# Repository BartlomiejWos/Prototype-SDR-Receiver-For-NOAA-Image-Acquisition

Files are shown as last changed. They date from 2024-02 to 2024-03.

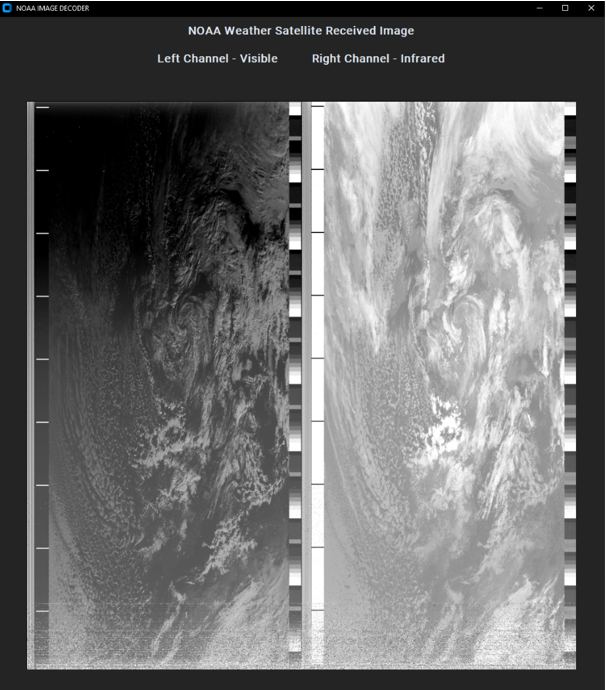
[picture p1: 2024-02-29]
images/decoder.png

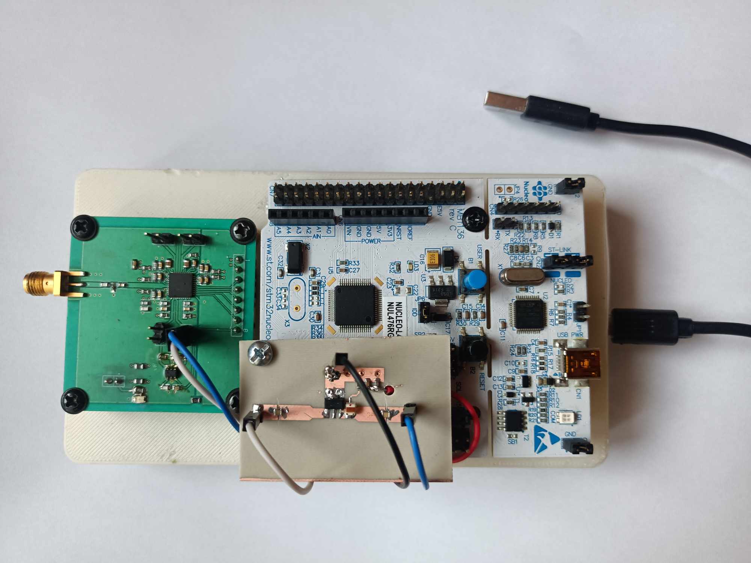
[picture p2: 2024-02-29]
images/sdr.jpg

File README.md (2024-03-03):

# Data acquisition from the NOAA meteoroligal satellite using DIY radio prototype based on the idea of Software Defined Radio (SDR) - Engineering Thesis Project   

## The purpose of this project was to design and fabricate a receiver, based on the idea of SDR, with appropriate software, to acquire weather images from NOAA's satellites (operating at 137 MHz).

This project is an example showing you how to create simple SDR receiver for narrowband applications. Parts of the project shows how do the following: 
* Create a radio front-end PCB using Direct Conversion Receiver (DCR) Integrated Circuit CMX994, MAX2607 (Local Oscillator - LO) and ADL5611 (LO amplifier).
* Analog-to-digital processing and interface handling using STM32.
* Creation of software application enabling the observation of the spectrum of received signals and signal processing to decode the received data into an image.
* All steps have been detailed in the engineering thesis in the Polish language.

## Complete Device:
sdr

## Software written in python for spectral analysis and signal recording:
gui

## NOAA image decoder:
decoder

## PCB layout of radio front-end:
layout

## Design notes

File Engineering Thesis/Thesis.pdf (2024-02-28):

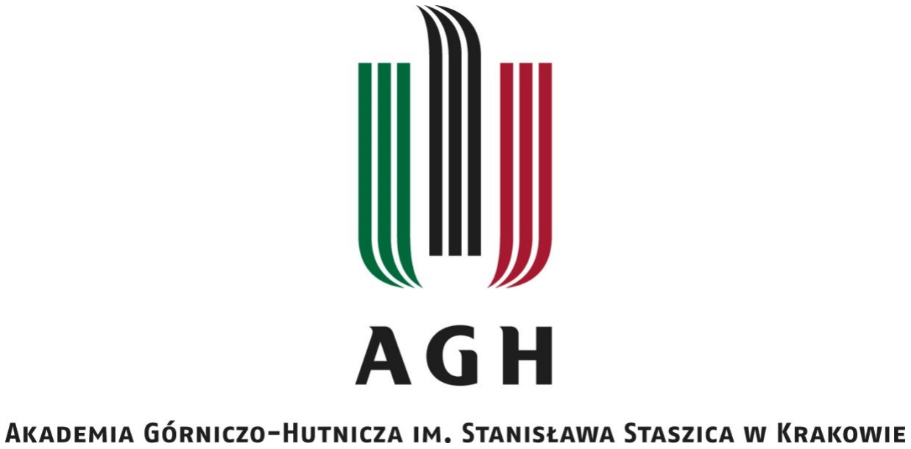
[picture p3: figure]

Wydział Informatyki, Elektroniki i Telekomunikacji

INSTYTUT ELEKTRONIKI

# Projekt dyplomowy

## Akwizycja danych z satelity meteorologicznego NOAA za pomocą prototypu radia bazującego na idei radia

definiowanego programowo (SDR).

## Data acquisition from the NOAA meteorological satellite using a radio prototype based on the idea of Software Defined

Radio.

Autor: | Bartłomiej Woś
Kierunek studiów: Elektronika i Telekomunikacja Opiekun pracy: dr inż. Robert Smolarz

Kraków, 2024

## Spis treści

1 Wstęp | 2
2 Model odbiornika definiowanego programowo | 3
3 Aplikacja komputerowa | 23
4 Badania i testy | 32
5 Podsumowanie | 37
Spis rysunków | 38
Spis tabel | 39
Literatura | 40
Załączniki | 43

## 1 Wstęp

Historia teledetekcji satelitarnej sięga połowy XIX wieku, kiedy to zostały wykonane pierwsze zdjęcia z balonu przez Gasparda Felixa Turnachon-Nadara [18].

Kolejnym kamieniem milowym było wykonanie serii zdjęć powierzchni Ziemi z wysokości ok. 120 km (czyli przekraczającej linię Karmana, będącą umowną

granicą między atmosferą Ziemi i przestrzenią kosmiczną) podczas lotu rakiety

balistycznej V2 [5]. W latach 60 XX wieku, Stany Zjednoczone rozpoczęły dwa

programy pozyskiwania zdjęć satelitarnych z kosmosu: wojskowy CORONA i cywilny TIROS (ang. Television Infrared Observation Satellite). Właśnie ten

ostatni został w 1978 roku przemianowany na program NOAA (ang. North

Oceanic and Atmospheric Adminstration). Seria satelitów TIROS-N/NOAA nadal

zapewnia codzienne obserwacje pogody na świecie. Satelity polarne NOAA krążą

po orbitach heliosynchronicznych, na wysokości ok. 790 - 870 km i okrążają Ziemię

14 razy dziennie. Ciekawostką jest to, że najstarszy z aktywnych satelitów -NOAA-15, jest na orbicie od 1998 roku. [13].

Celem niniejszej pracy inżynierskiej było zaprojektowanie oraz wykonanie odbiornika, bazującego na idei radia definiowanego programowo SDR (ang.

Software Defined Radio), wraz ze stosownym oprogramowaniem, umożliwiającym

pozyskanie zdjęć pogodowych z satelit NOAA starszego typu (pracujących na

częstotliwości 137 MHz). Praca składa się ze wstępu, dwóch rozdziałów

teoretycznych i jednego rozdziału praktycznego opisującego przeprowadzone

badania nad wykonanym urządzeniem oraz podsumowania. W rozdziale pierwszym

przeprowadzono analizę indywidualnych bloków funkcjonalnych służących do

akwizycji danych, w rozdziale drugim omówiono realizacje sprzętową i działanie

zaimplementowanej aplikacji komputerowej, natomiast rozdział trzeci został w

całości poświęcony przeprowadzonym pomiarom i testom zaprojektowanego

urządzenia. W zakończeniu przedstawiono podsumowanie wykonanych badań oraz

propozycje udoskonalenia zaprojektowanego urządzenia.

## 2 Model odbiornika definiowanego programowo

W niniejszym rozdziale skupiono się na analizie poszczególnych bloków

funkcjonalnych | służących | do | akwizycji | danych | odbieranych | z | satelit

meteorologicznych NOAA. W każdym podrozdziale przedstawiono kluczowe

elementy opracowanego systemu akwizycji, wybrane rozwiązania i dobór

oszacowanych wartości elementów. W podrozdziałach zawarto również niezbędne

symulacje oraz charakterystyki ułatwiające analize poszczególnych bloków.

### 2.1 Schemat blokowy

Na rysunku 2.1 przedstawiono schemat blokowy projektowanego urządzenia.

Fundamentalną rolę w rozpatrywanej strukturze pełni układ odbiornika o bezpośredniej przemianie częstotliwości DCR (ang. Direct Conversion Receiver ),

który jest jednym z popularniejszych rozwiązań stosowanych w odbiornikach
radiowych | [19]. | Proces | bezpośredniej | przemiany | częstotliwości | oznacza

sprowadzenie sygnału do pasma podstawowego (ang. Baseband). W kontekście

radia definiowanego programowo istotnym etapem jest jego dalsze przetworzenie

na reprezentacje cyfrową oraz transmisja do urządzenia docelowego takiego jak

komputer. Zabieg ten ma na celu dalszą obróbkę i dekododowanie pozyskanych

danych. | Odpowiednim | układem | zapewniającym | te | funkcjonalności | jest

mikrokontroler, którego zadaniem jest obsługa użytego bloku DCR oraz

komumunikacja z komputerem. Bloki funkcjonalne wchodzące w skład całego

systemu akwizycji, szczegółowo opisano w kolejnych podrozdziałach niniejszej

pracy.

Rysunek 2.1: Schemat blokowy projektowanego urządzenia typu SDR.

2.2 | Blok | odbiornika | bezpośredniej | przemiany

częstotliwości.

Omawiany | moduł | stanowi | jeden | z | najważniejszych | komponentów

projektowanego urządzenia odbiorczego. Jego sercem jest układ scalony CMX994,

pracujący w trybie DCR. W odróżnieniu od odbiorników heterodynowych z

podwójną przemianą częstotliwości, wybór architektury DCR przekłada się na

mniejszą złożoność toru radiowego. Dodatkowo przykładowe zastosowania układu

obejmują obszary takie jak radia definiowane programowo oraz komunikacja satelitarna [14], co sprawia, że wybrany element idealnie wpasowuje się w określone

założenia. Rysunek 2.2 przedstawia topologię układu CMX994 [14]. Rozpatrując

schemat mozna wyróżnić bloki funkcjonalne takie jak:
- zastosowany na wejściu niskoszumny wzmacniacz LNA (ang. Low Noise

Amplifier )
- tor przemiany częstotliwości zbudowany z dwóch mieszaczy, czterech filtrów

oraz układów wzmacniających
- rekonfigurowalny obwód oscylatora lokalnego
- wewnętrzny kontroler odpowiedzialny za komunikacje z układem

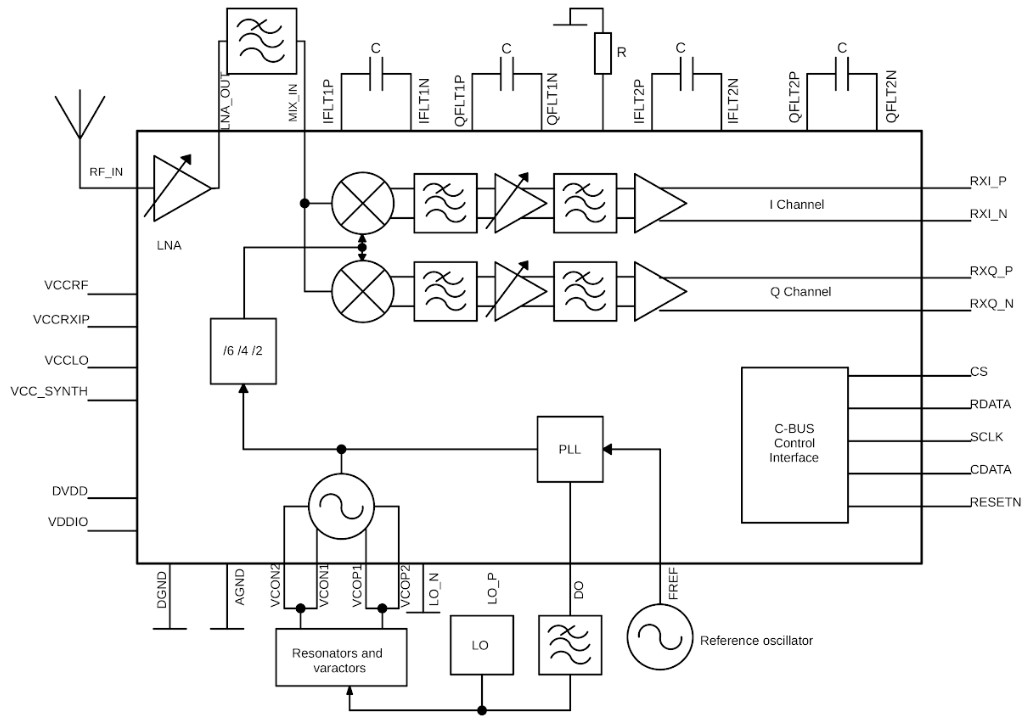
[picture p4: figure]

Rysunek 2.2: Schemat blokowy układu scalonego CMX994 [14].

Niezbędnym krokiem w celu prawidłowej pracy układu jest skonfigurowanie

rejestrów kontrolnych za pomocą magistrali C-BUS. Magistrala ta umożliwa komunikację z mikrokontrolerem za pomocą interfejsu SPI (ang. Serial Peripherial

Interface). Najważniejszymi rejestrami układu są General Control (Tabela 2.1)

oraz Rx Control (Tabela 2.2). Ich konfiguracja powinna być wykonana w

pierwszym | etapie | zintegrowania | projektowanego | odbiornika | DCR | z
mikrokontrolerem. Strukturę rejestrów na bazie noty katalogowej [14] ukazano

poniżej:

bit 7 | bit 6 | bit 5 | bit 4 | bit 3 | bit 2 | bit 1 | bit 0
En Bias | Freq2 | Freq1 | LP | VCOEN | PLLEN | RXEN | TXEN

Tabela 2.1: Rejestr General Control Układu Scalonego CMX944 [14].

bit 7 | bit 6 | bit 5 | bit 4 | bit 3 | bit 2 | bit 1 | bit 0
Mix Pwr | IQ Pwr | LNA Pwr | ACR Flt2 | ACR Flt1 | DC Range | DIV2 | DIV1

Tabela 2.2: Rejestr Rx Control Układu Scalonego CMX944 [14].

Detale dotyczące konkretnych ustawień oraz funkcji tych rejestrów można

znaleźć w dalszych sekcjach, w których szczegołówo omówiono istotne bloki

układu. Schemat elektryczny układu przedstawiono w załączniku 1.

### 2.2.1 Blok przemiany częstotliwości w układzie CMX994

Blok przemiany częstotliwości zastosowany w układzie CMX994 został

przedstawiony na Rysunku 2.3. Składa się on z dwóch torów radiowych dzięki, którym uzyskuje się dwie składowe: kwadraturową Q (ang. Quadrature) i

synfazową I (ang. In-phase). W kontekście cyfrowego przetwarzania sygnałów i

radia definiowanego programowo, odnosi się to do dwóch sygnałów przesuniętych w fazie o 90 stopni [12]. Rozpatrywany układ jest odbiornikiem z bezpośrednią

przemianą częstotliwości, toteż w pierwszej kolejności sygnał radiowy RF

pojawiący się na wejściu MIX IN jest mieszany z sygnałem oscylatora lokalnego LO (ang. Local Oscillator ) za pomocą mieszaczy diodowych. Po zestrojeniu

sygnału LO z sygnałem radiowym, w wyniku przemiany częstotliwości w ”dół”

uzyskuje się składowe Q oraz I o widmach przesuniętych do pasma podstawowego [19].

Aby umożliwić prawidłowe działanie bloku, układ mieszacza musi zostać

programowo włączony poprzez interfejs komunikacyjny. Służą do tego bity 1 i 7 rejestru General Control (Tabela 2.1) oraz bit 7 rejestru Rx Control (Tabela 2.2).

Tor radiowy kanałów IQ pasma podstawowego zawiera dwa dolnoprzepustowe

stopnie filtrujące oraz układy wzmacniające opisane w podrozdziale 2.2.3.

Wyprowadzenia obu kanałów zaprojektowano jako pary różnicowe, co należy

uwzględnić przy doborze mikrontrolera. Bloki filtrujące pozwalają na precyzyjną

konfiguracje | szerokości | pasma | w | odstępach | międzykanałowych | równych
odpowiednio 6.25 kHz, 12.5 kHz i 25 kHz [14]. Aby taka regulacja była możliwa,

dobrano odpowiednio kondesatory C18 − C21 ustalające częstotliwości graniczne

filtrów.

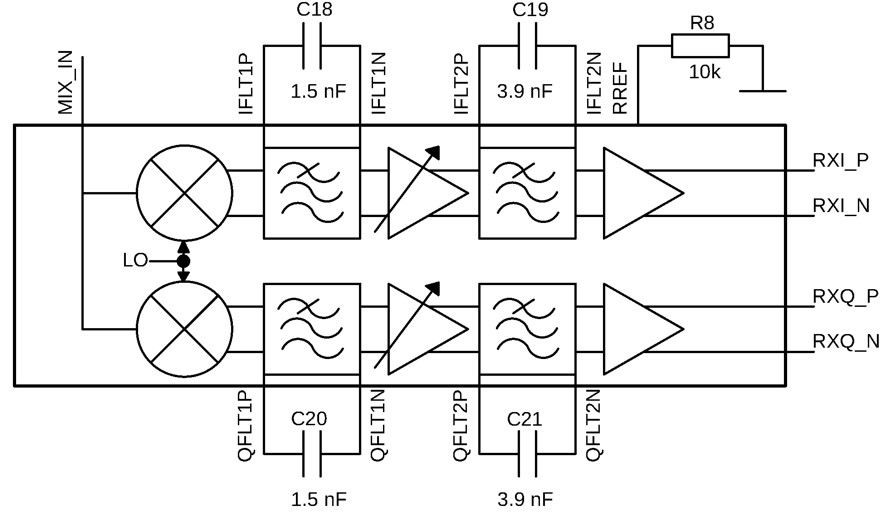
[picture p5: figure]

Rysunek 2.3: Blok przemiany częstotliwości układu scalonego CMX994 [14].

Pierwszy filtr umieszczony za układem mieszającym został zaprojektowany w

celu redukcji sygnałów blokujących. Nie jest on sterowany programowo i w

standardowej konfiguracji jest ustawiany na 4 - krotność wymaganej szerokości

pasma. Dla maksymalnego odstepu międzykanałowego tj. 25 kHz, częstotliwość przy której sygnał jest tłumiony o 3 dB powinna wynosić około 100 kHz [14].

Wartości elementów oszacowano za pomocą wzoru (2.1) dostępnego w nocie

katalogowej [14]:

C18,20 =

1
2π · f3dB · 20, 000

(2.1)

gdzie:

C18,20 - oszacowana wartość elementu

f3dB - częstotliwość graniczna filtru

Drugi filtr umieszczony za układem wzmacniającym, przeznaczony jest do

działania w pobliżu pasma podstawowego. Jego celem jest maksymalne

ograniczenie interferencji pochodzących z sąsiednich kanałów. Częstotliwość odcięcia filtru powinna wynosić między 30 % a 40 % szerokości najmniejszego

odbieranego pasma tj. 6.25 kHz oraz może być regulowana cyfrowo z

uwzględnieniem współczynnika skalującego 1:2:4 za pomocą bitów 3 - 4 rejestru Rx Control (Tabela 2.2). [14]. Konfiguracje bitów oraz odpowiadający im

współczynnik skalujący przedstawiono w Tabeli 2.3. Wartości kondesatorów, analogicznie jak w przypadku pierwszego filtru, obliczono za pomocą wzoru (2.2)

umieszczonego w nocie katalogowej [14]:

C19,21 =

1
2π · f3dB · 12, 000

(2.2)

gdzie:

C19,21 - oszacowana wartość elementu

f3dB - częstotliwość graniczna filtru

ACR flt2 | ACR flt1 | Współczynnik skalujący częstotliwości granicznej
0 | 0 | 2
0 | 1 | 4
1 | 0 | 8
1 | 1 | wartość zarezerwowana

Tabela 2.3: Współczynnik skalujący w zależności od konfiguracji bitów 3 - 4 rejestru Rx Control.

Rysunek 2.4 przedstawia charakterystyki amplitudowo - częstotliwościowe filtru

w zależności od konfiguracji bitów 3 - 4 rejestru Rx Control.

Rysunek 2.4: Charakterystyki amplitudowo – częstotliwościowe filtru w zależności od konfiguracji współczynnika skalującego [14].

### 2.2.2 Sekcja lokalnego oscylatora w układzie CMX944

Układ oscylatora lokalnego zwanego również heterodyną jest odpowiedzialny

za generowanie sygnału sinusoidalnego, który bierze udział w przemianie

częstotliwości razem z układem mieszacza. Odbiornik scalony CMX994 posiada

zintegrowany układ generatora o przestrajanej napięciowo częstotliwości VCO (ang. Voltage Controlled Oscillator ). Częstotliwość podstawowa wewnętrznego

VCO, jest ustalana za pomocą zewnętrznych elementów indukcyjnych oraz waraktorów [14]. Sekcja lokalnego oscylatora zawiera pętle synchronizacji fazowej

PLL (ang. Phase Locked Loop), którą można aktywować za pomocą bitu 2 rejestru

General Control (Tabela 2.1). Blok ten może współpracować zarówno z

wbudowanym lub zewnętrznym układem VCO. Podczas projektowania urządzenia

stwierdzono, że dostrojenie wewnętrznego VCO mogłoby być problematyczne, co

skłoniło | do | zastosowania | zewnętrznego | układu | scalonego. | Dodatkowo,

zrezygnowano z użycia układu PLL. Jako układ oscylatora sterowanego napięciem,

wybrano układ scalony z serii MAX2605 - 2609. Są to generatory sinusoidalne

pracujące w zakresie 45 MHz - 650 MHz, zaprojektowane specjalnie dla

przenośnych urządzeń komunikacji bezprzewodowej. Posiadają wbudowane

kondensatory sprzężenia zwrotnego oraz waraktory i z tego powodu jedynie zewnętrzna cewka jest wymagana do ustawienia częstotliwości oscylacji [9]. W celu

poprawnej obsługi zewnętrznego układu LO, należy aktywować blok VCO za pomocą bitu 3, oraz skonfigurować bity 5 - 6 rejestru General Control (Tabela

2.1). Odpowiadają one za dostosowanie amplitudy sygnału lokalnego oscylatora w

celu utrzymania równowagi fazy i parametrów szumowych mieszaczy odbiornika w wybranym zakresie częstotliwości [14]. Konfiguracje bitów 5 - 6 oraz

odpowiadający im zakres częstotliwości układu LO pokazano w poniższej tabeli:

bit Freq1 | bit Freq2 | Zakres częstotliwości LO (MHz)
0 | 0 | 100 - 150
0 | 1 | 150 - 300
1 | 0 | 300 - 700
1 | 1 | 700 - 100

Tabela 2.4: Zakres częstotliwości w zależności od konfiguracji bitów 5 - 6 rejestru General Control.

Przy wyborze odpowiedniego układu pełniącego role heterodyny, należy

również uwzględnić dzielnik częstotliwości w sekcji oscylatora. Jest on ustawiany

za pomocą bitów 1 - 2 rejestru General Control. W projektowanym urządzeniu,

omawiany dzielnik został ustawiony tak, aby uzyskać minimalny podział częstotliwości wynoszący dwa. Tabela 2.5 prezentuje konfiguracje rejestru i

uzyskiwane wartości podziału.

bit DIV2 | bit DIV1 | Dzielnik częstotliwości LO (MHz)
0 | 0 | 2
0 | 1 | 4
1 | 0 | 6
1 | 1 | wartość zarezerwowana

Tabela 2.5: Dzielnik częstotliwości w zależności od konfiguracji bitów 1-2 rejestru RX Control.

W związku z wyborem dzielnika, zdecydowano się na wybór takiego VCO,

którego zakres częstotliwości jest co najmniej dwukrotnie większy niż docelowa częstotliwość odbioru (137 MHz). Układem spełniającym te założenia jest

MAX2607 pracujący w zakresie 150 MHz - 300 MHz [9]. Ze względu na brak

informacji o nominalnej mocy sygnału wyjściowego w nocie katalogowej układu [9],

postanowiono przeprowadzić pomiary wybranego elementu. Wyniki pomiarów wykazały, że układ osiąga maksymalną wartość mocy POUT = −20 dBm co nie

jest wystarczające do prawidłowego funkcjonowania mieszaczy częstotliwości

znajdujących się w układzie CMX994. W celu zwiększenia mocy sygnału

wyjściowego, zdecydowano się rozbudować układ LO o element wzmacniający. Do

tego celu wykorzystano scalony wzmacniacz ADL5611, charakteryzujący się stałym

wzmocnieniem wynoszącym 20 dB oraz szerokim pasmem pracy wynoszącym 30 MHz - 6 GHz [6]. Schemat ideowy obu układów pokazano na Rysunku 2.5.

Wartość cewki L4, ustalającej częstotliwość pracy układu MAX2607 dobrano za

pomocą charakterystyki indukcyjności od częstotliwości zamieszczonej w nocie katalogowej [9] (strona 7).

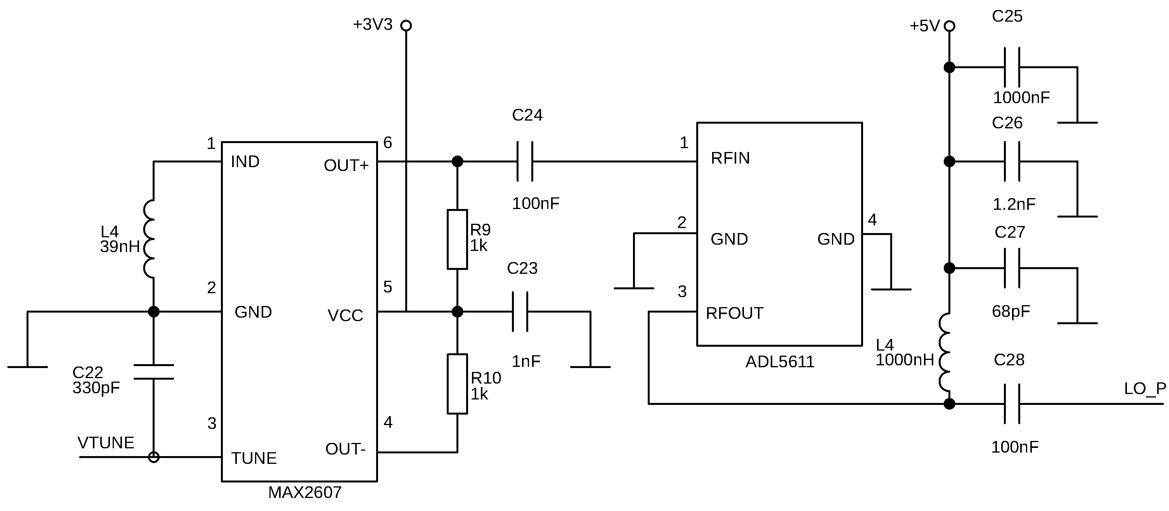
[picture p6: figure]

Rysunek 2.5: Układ oscylatora lokalnego składającego się z generatora VCO - MAX2607 oraz szerokopasmowego wzmacniacza ADL5611.

W celu poprawnego wzmacniania sygnału generowanego przez VCO, układ

ADL5611 musi zostać skonfigurowany do pracy w paśmie 30 MHz - 500 MHz. Aby

to osiągnąć, należy dobrać odpowiednie wartości kondesatorów odsprzęgających

C25, C26, C27 oraz cewki L5. Wartości tych elementów dobrano na bazie informacji zamieszczonych w nocie katalogowej [6], a następnie skorygowano za

pomocą symulacji parametru S21, który można potraktować jako małosygnałowy

współczynnik wzmocnienia układu. Dla dwukrotności docelowej częstotliwości

odbioru - 274 MHz, wzmocnienie wynosi ok. 21 dB.

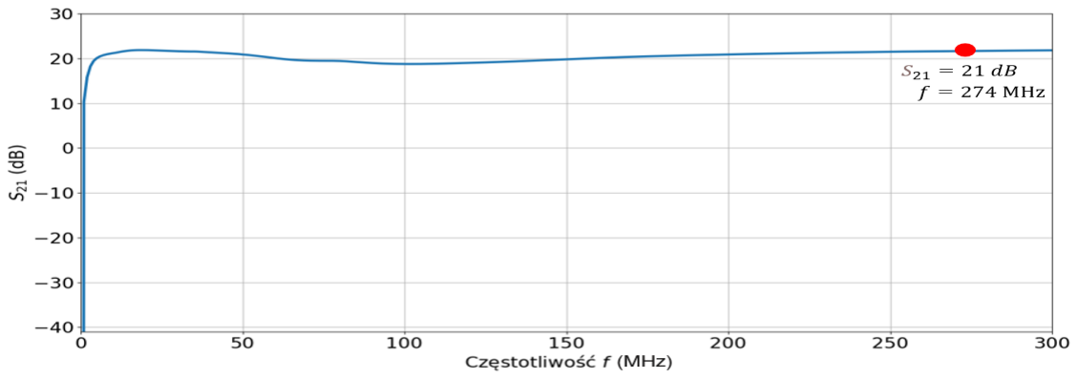
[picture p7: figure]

Rysunek 2.6: Charakterystyka parametru S21 układu ADL5611.

Następnie przeprowadzono pomiary dla obwodu złożonego z układów

MAX2607 i ADL5611, skupiajac się głównie na pomiarze częstotliwości f oraz

mocy wyjściowej POUT w funkcji napięcia sterującego VT UNE podawanego z

wyjścia mikrokontrolera. Charakterystyki zmierzono w zakresie od 0.4 V do 2.4 V,

ponieważ zgodnie z notą katalogową układu MAX2607 widać w nim największe zmiany częstotliwości generowanego sygnału [9].

Do wykonania pomiarów wykorzystano następujące urządzenia pomiarowe:
- Zasilacz Laboratoryjny LPS-305 firmy Motech: zakres napięcia -30 V - 30 V;

zakres prądu 0 - 2.5 A; rozdzielczość 10 mV / 1 mA; błąd śledzenia 20 mV / 5

mA
- Analizator Widma FSV marki Rohde&Schwarz: zakres częstotliwości 10 Hz -

4 GHz; szum fazowy na poziomie –106 dbc; średni poziom szumów -155 dBm

Rysunek 2.7 przedstawia obwód wykorzystany w pomiarach.

Docelową wartość częstotliwości (274 MHz) uzyskano dla napięcia sterującego

około 0.6 V, co pokazano na wykresie z Rysunku 2.8. Poprzez rozbudowanie

układu heterodyny o wzmacniacz ADL5611, zwiększono moc sygnału wyjściowego.

Po tej modyfikacji LO, moc wyjściowa zawiera się w zakresie od -12 dBm do -10 dBm (Rysunek 2.9). Zatem dla wymaganej częstotliwości, uzyskano wzrost mocy z

wartości -20 dBm (obwód bez wzmacniacza) do -11 dBm (ze wzmacniaczem).

Wartość ta jest wystarczająca do prawidłowej prawidłowej pracy mieszaczy w

układzie CMX944.

Rysunek 2.7: Schemat Pomiarowy układu oscylatora lokalnego.

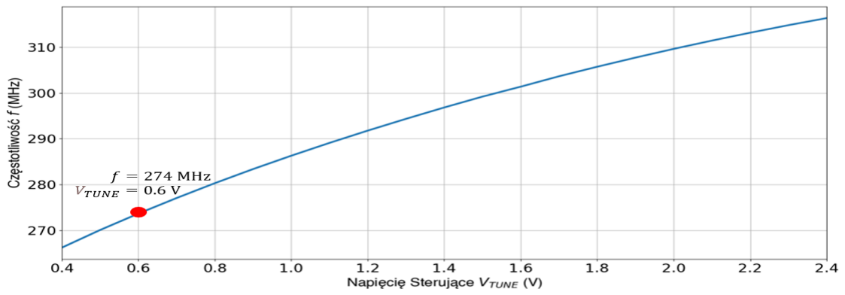
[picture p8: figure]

Rysunek 2.8: Charakterystyka przedstawiająca zależność między częstotliwością sygnału generowanego przez układ MAX2607, a napięciem sterującym VT UNE.

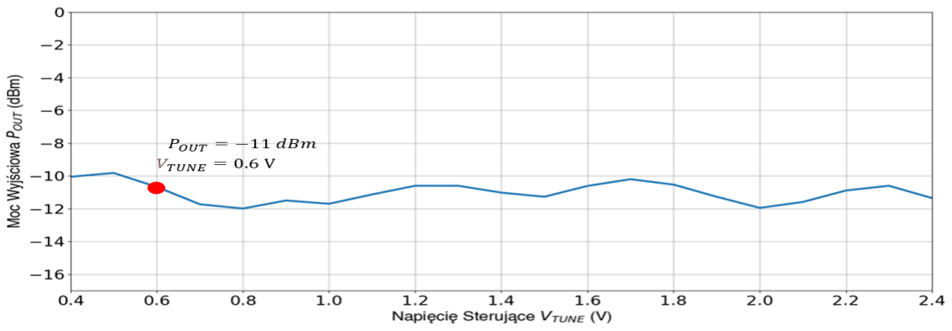
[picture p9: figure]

Rysunek 2.9: Charakterystyka mocy wyjściowej w funkcji napięcia sterującego układu LO ze wzmacniaczem ADL5611.

### 2.2.3 Bloki wzmacniające w układzie CMX944

Układ odbiornika bezpośredniej przemiany częstotliwości CMX944 został

wyposażony w elementy wzmacniające, mające na celu zwiększenie możliwości układu w zakresie odbioru słabych sygnałów [4]. Pierwszym stopniem

wzmacniającym umieszczonym w torze radiowym jest układ LNA. Schemat ideowy

stopnia wejściowego zawierającego omawiany wzmacniacz oraz układ dopasowania

anteny, zaprezentowano na Rysunku 2.10.

Rysunek 2.10: Wzmacniacz niskoszumny odbiornika scalonego CMX994 oraz układ dopasowania anteny [14].

Wzmacniacz niskoszumny zastosowany na wejściu radioodbiornika pełni

kluczową rolę. Po pierwsze, jest odpowiedzialny za wzmacnianie sygnałów o małej

mocy, a po drugie - jego właściwości szumowe decydują o całkowitym szumie w

układzie co też przekłada się m.in. na czułość odbiornika. Wzmacniacz został

wyposażony w mozliwość cyfrowej konfiguracji, za pomocą rejestru sterującego Rx Gain [14]. Strukturę bitów rejestru przedstawiono w Tabeli 2.6. Wzmacniacz ten

może być skonfigurowany w jednym z dwóch dostępnych ustawień impedancji wyjściowej: 50 Ω lub 100 Ω za pomocą bitu 3 rejestru Rx Gain (Tabela 2.6).

Opcja 100 Ω przeznaczona jest do użytku przy częstotliwościach niższych niż 450 MHz [14], co sprawia, że jest właściwym wyborem dla odbioru sygnałów NOAA

zakodowanych na 137 MHz.

bit 7 | bit 6 | bit 5 | bit 4 | bit 3 | bit 2 | bit 1 | bit 0
GS1 | GS0 | LNA GAIN2 | LNA GAIN1 | LNA Z0 | G2 | G1 | G0

Tabela 2.6: Rejestr RX Gain Układu Scalonego CMX944 [14].

Przy ustawieniu impedancji wyjściowej równej 100 Ω , należy dobrać układ

dopasowania anteny zapewniający jak najmniejsze straty mocy na wejściu wzmacniacza. W tym celu, bazując na informacjach zawartych w nocie katalogowej [14], odpowiednio dobrano wartości elementów L1 , C15 oraz C16 .

Zależność współczynnika odbicia S11 od częstotliwości dla omawianego układu

dopasowania przedstawiono na Rysunku 2.11.

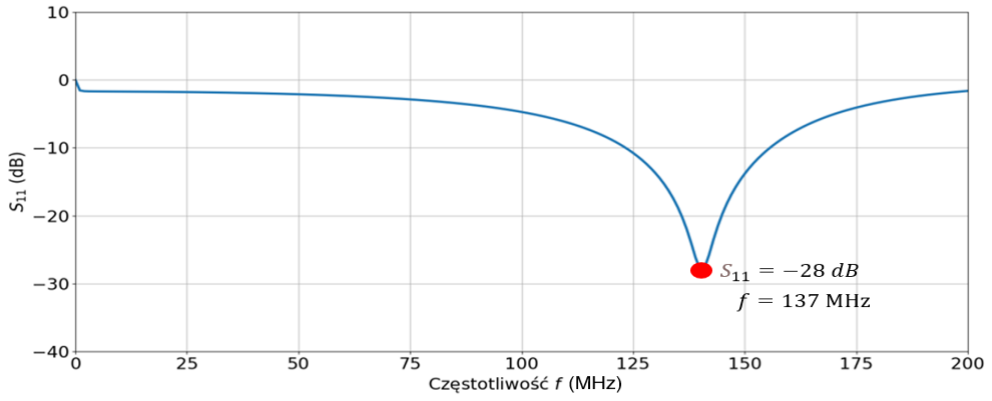
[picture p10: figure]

Rysunek 2.11: Charakterystyka amplitudowo-czestotliwościowa współczynnika odbicia S11 .

Układ umożliwia regulacje nominalnego wzmocnienia za pomocą bitów 6 - 7 rejestru Rx Gain zakresie 6.0 dB do 8.8 dB (Tabela 2.7). Dodatkowo, bity 4 - 5

rejestru Rx Gain (Tabela 2.6) bezpośrednio kontrolują wartość wzmocnienia układu

w zakresie -18 dB do -0 dB z krokiem co 6 dB. Umożliwia to regulację nominalnego

wzmocnienia poprzez odjęcie od niego wartości wybranej wartości, co pokazano w

Tabeli 2.8.

bit GS1 | bit GS0 | Nominalne wzmocnienie G (dB)
0 | 0 | + 6.0
0 | 1 | + 6.7
1 | 0 | + 7.4
1 | 1 | + 8.8

Tabela 2.7: Wzmocnienie układu LNA w zależności od konfiguracji bitów 6 - 7 rejestru Rx Gain.

bit LNA GAIN2 | bit LNA GAIN1 | Wzmocnienie G (dB)
0 | 0 | Nominalne Wzmocnienie - 0
0 | 1 | Nominalne Wzmocnienie - 6
1 | 0 | Nominalne Wzmocnienie - 12
1 | 1 | Nominalne Wzmocnienie - 18

Tabela 2.8: Wzmocnienie układu LNA w zależności od konfiguracji bitów 4 - 5 rejestru Rx Gain.

Wyjście LNA zostało podłączone z układem mieszacza poprzez filtr pasmowo przepustowy typu LC, złożony z kondensatora C17 i cewki L2 (Rysunek 2.10).

Wartości elementów dobrano na podstawie noty katalogowej [14] dla pasma

przenoszenia około 100 MHz. Częstotliwość graniczna filtru fc na podstawie

załączonego poniżej współczynnika toru transmisyjnego S21 wynosi około 60 MHz (Rysunek 2.12).

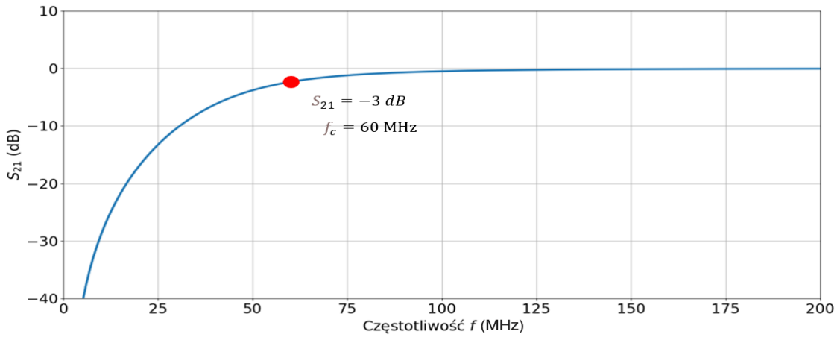
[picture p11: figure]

Rysunek 2.12: Charakterystyka Amplitudowo-Czestotliwościowa współczynnika transmisji S21 .

Sekcja pasma podstawego zawiera dwa stopnie wzmacniające (Rysunek 2.3).

Pierwszy wzmacniacz jest układem o zmiennym wzmocnieniu VGA (ang. Variable

Gain Amplifier ). Nominalne wzmocnienie układu wynosi 15 dB i może być

regulowane z krokiem co 6 dB w zakresie -27 dB do 15 dB za pomocą bitów 0 - 2 rejestru Rx Gain (Tabela 2.6). Konfiguracje bitów dla sekcji VGA pokazano w

Tabeli 2.9. Drugi wzmacniacz ma stałe wzmocnienie wynoszące 20 dB i jest

ostatnim elementem toru radiowego. Sekcja wzmacniająca układu przemiany

częstotliwości może zostać wyłączona za pomocą bitu 7 rejestru General Control (Tabela 2.1).

bit G2 | bit G1 | bit G0 | Wzmocnienie mocy GP
1 | 1 | 1 | -42 dB
1 | 1 | 0 | -36 dB
1 | 0 | 1 | -30 dB
1 | 0 | 0 | -24 dB
0 | 1 | 1 | -18 dB
0 | 1 | 0 | -12 dB
0 | 0 | 1 | -6 dB
0 | 0 | 0 | -0 dB

Tabela 2.9: Wzmocnienie układu VGA w zależności od konfiguracji bitów 0 - 2 rejestru Rx Gain.

Opisane powyżej mechanizmy kontroli wzmocnienia zarówno w układzie

niskoszumnego LNA jak i w sekcji pasma podstawowego pozwalają na regulacje

wzmocnienia w zakresie 60 dB. Dzięki takiej funkcjonalności układ może być

efektywnie wykorzystywany przy różnorodnych aplikacjach.

### 2.2.4 Układ zasilania

Urządzenie musi posiadać co najmniej dwa źródła zasilania. Dla układu

scalonego CMX944 niezbędne jest dodatnie napięcie z zakresu 3.0 V - 3.6 V, natomiast zalecane jest użycie napięcia o wartości 3.3 V [14]. Układ oscylatora

lokalnego może być zasilany napięciami z zakresu 2.7 V - 5.5 V, wyższe napięcie

wpływa tylko na przesunięcie częstotliwości podstawowej generowanej przez VCO.

Najprostszym rozwiązaniem jest zasilać te układy z jednego źródła napięcia o

wartości 3.3 V. Z uwagi na fakt że wyprowadzenie LO zostało podłączone do

układu scalonego CMX944 poprzez układ wzmacniający ADL5611, który musi być zasilany ze źródła o wartości 5 V (patrz: Rysunek 2.5), projektowany układ

odbiornika DCR potrzebuje dwóch dodatnich napięć tj. 3.3 V i 5 V w celu

prawidłowego działania. Większość mikrokontrolerów dostępnych na rynku posiada

wyprowadzenia pozwalające na pracę z wyżej wymienionymi wartościami napięć,

co | umożliwia | łatwe | zasilanie | projektowanego | układu | z | wyprowadzeń

mikrokontrolera. Szacunkowe wartości prądów i napięć zasilających poszczególnych

układów zamieszczono w Tabeli 2.10. Są to wartości podawane przez producentów

układów scalonych.

Lp. | Element | Napięcie zasilania Vcc (V) | Prąd zasilania I (mA)
1. | CMX994 | 3.3 | 70
2. | MAX2607 | 3.3 | 2.1
3. | ADL5611 | 5.0 | 94

Tabela 2.10: Zestawienie napięć i prądów zasilania wykorzystanych układów scalonych.

Zakłócenia o niskiej częstotliwości dla układu scalonego CMX944 usunięto za pomocą kondensatorów odsprzęgających (Rysunek 2.13), których wartości dobrano

na podstawie noty katalogowej [14]. Dodatkowo, aby zapewnić filtracje

ewentualnych zakłóceń wynikających z zasilania zarówno części analogowej jak i

cyfrowej jednym źródłem, na liniach zasilających układu zastosowano koraliki

ferytowe. Są to elementy charakteryzyjące się niewielką indukcyjnością,

przeznaczone | do | odfiltrowywania | zakłóceń | o | dużych | częstotliwościach,
generowanych np. przez szybkie układy cyfrowe [21].

Rysunek 2.13: Schemat lini zasilających układu scalonego CMX944.

### 2.3 Mikrokontroler

Z analizy zawartej w poprzednich podrozdziałach wynika, że jednym z

niezbędnych elementów mikrokontrolera jest obsługa interfejsu SPI, umożliwiająca

konfiguracje odbiornika CMX944. W celu zapewnienia najbardziej efektywnego

przetwarzania sygnału radiowego, układ mikrokontrolera powinien dysponować co

najmniej dwoma dwukanałowymi przetwornikami analogowo - cyfrowymi ADC (ang. Analog to Digital Converter ), lub jednym czterokanałowym. Szczególną

uwagę zwrócono na możliwość konfiguracji przetworników w trybie różnicowym, ze względu na wyprowadzenia kanałów IQ układu przemiany częstotliwości (patrz:

podrozdział 2.2). Układ Mikroprocesorowy, powinien również posiadać wbudowany

przetwornik cyfrowo - analogowy DAC (ang. Digital to Analog Converter ), aby

przestrajać częstotliwość lokalnego oscylatora. Ważnym elementem jest także

przekazywanie przetworzonych próbek do komputera poprzez dedykowany interfejs

do komunikacji. W tym przypadku szczególny nacisk został położony na zapewnienie możliwości komunikacji poprzez interfejs USB (ang. Universal Serial

Bus, co wynika z potrzeby przesyłania danych przy częstotliwości kilkudziesięciu

kHz. Pasującym do tego opisu układem okazała się płyta deweloperska
NUCLEO-L476RG | [17] | zawierająca | mikrokontroler | STM32, | firmy

STMicroelectronics przedstawiona na Rysunku 2.14.

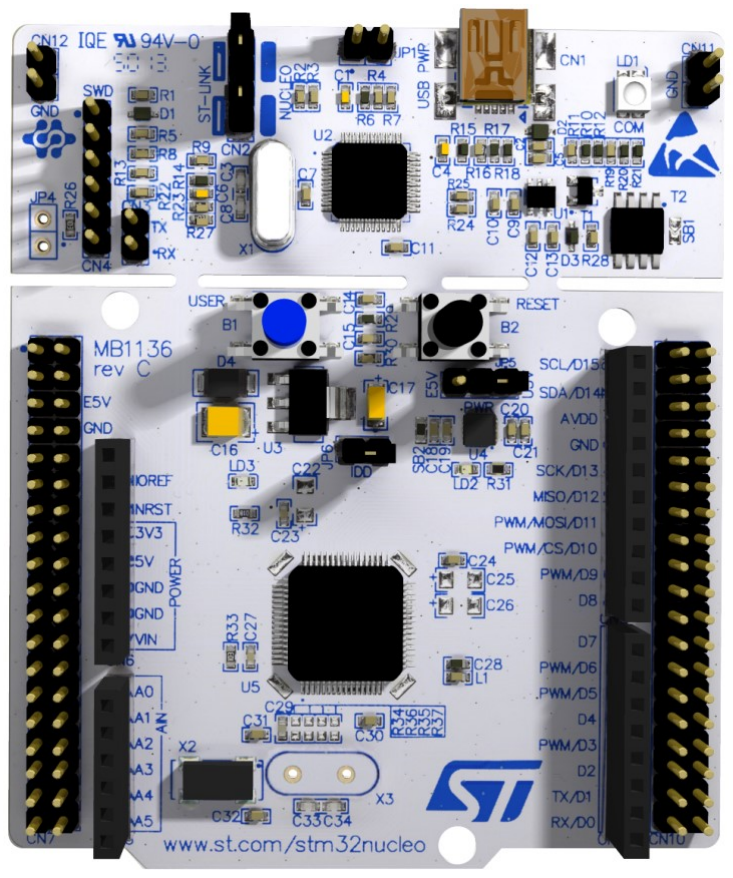
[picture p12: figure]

Rysunek 2.14: Zdjęcie płyty deweloperskiej Nucleo z noty katalogowej urządzenia [17].

Poniżej przedstawiono wybrane elementy specyfikacji techicznej w oparciu o notę katalogową mikrokontrolera [17]:
- Rdzeń: ARM Cortex M4 32 - bit
- Częstotliwość taktowania: 80 MHz
- Pamięć programu Flash: 1 MB
- Pamięć SRAM: 128kB
- DMA:14 Kanałów
- Interfejsy: 3 x SPI, 1 x USB OTG
- 3 x przetwornik ADC: 12 - bit
- 2 x przetwornik DAC: 12 - bit
- Port do programowania/debugowania

W kolejnych sekcjach przedstawiono wykorzystane moduły mikrokontrolera.

Skupiono się głównie na procesie integracji wbudowanych urządzeń peryferyjnych z

projektowanym odbiornikiem DCR. Każda sekcja obejmuje omówienie zarówno

sposobu połączeń, jak i niezbędnych ustawień do zapewnienia poprawnego

działania całego urządzenia. Schemat ideowy połączenia układu mikrontrolera z

projektowanym urządzeniem odbiorczym umieszczono w Załączniku 2. Ostatni

podrozdział zawiera opis działania niezbędnego programu sterującego wszystkich

wykorzystanych peryferyriów mikrontrolera.

### 2.3.1 Interfejs SPI

Jak już wspomniano wielokrotnie, układ CMX994 komunikuje się z resztą

urządzenia za pomocą interfejsu SPI. Toteż, w pierwszej kolejności należy

skonfigurować odpowiednio ten interejs. W tym celu należy ustawić mikrokontroler jako urządzenie nadrzędne (Master) pracujące w trybie full - dupleks (możliwość

nadawania i odbioru w tym samym czasie) [10]. Sposób połączenia układu

peryferyjnego SPI mikrokontrolera z interfejsem komunikacyjnym C-BUS układu

scalonego CMX944 pokazano na Rysunku 2.15.

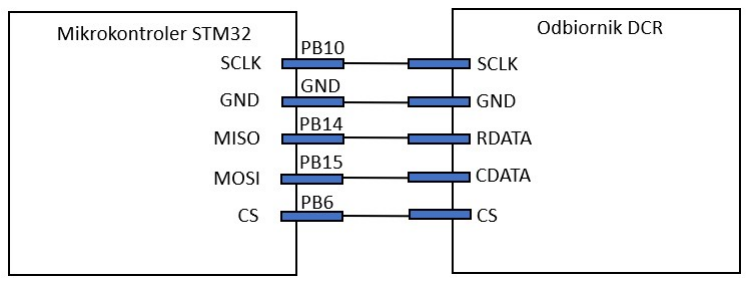
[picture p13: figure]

Rysunek 2.15: Schemat połączenia układu SPI mikrokontrolera z interfejsem C-BUS układu CMX944.

Aby zapewnić poprawną komunikację z układem odbiornika (Slave), którym

jest układ CMX994, konieczne jest odpowiednie dostosowanie parametrów

transmisji mikrokontrolera zgodnie z przebiegami czasowymi magistrali C-BUS umieszczonymi w nocie katalogowej [14]. W Tabeli 2.11 przedstawiono konkretne

wartości parametrów dostosowane do wymagań układu CMX944.

Parametr | Wartość
Rozmiar Ramki | 8-bit
Pierwszy Bit | MSB (Najbardziej Znaczący Bit)
Baud Rate | 1.25 Mbit/s
Polaryzacja zbocza | Zegar niski (low)
Faza | Pierwsze zbocze zegara (1 Edge)

Tabela 2.11: Parametry transmisji mikrokontrolera.

W celu rozpoczęcia transmisji, konieczne jest odpowiednie sterowanie wejściem CS ( ang. Chip Select) po stronie układu nadrzędnego (mikrokontroler). Obsługa

tego wejścia odbywa się programowo, gdzie przed każdą transmisją niezbędne jest ustawienie go w stan niski (logiczne ”0”). Po zakończeniu komunikacji wejście należy

ustawić w stan wysoki (logiczne ”1”), co uniemożliwi dalszą komunikacje z układem

peryferyjnym.

### 2.3.2 Przetworniki ADC i DAC

W | kontekście | przetwarzania | sygnału | radiowego | na | sygnał cyfrowy,

konfiguracja tego bloku jest kluczowa do precyzyjnej rekonstrukcji odbieranego

sygnału. Maksymalna rozdzielczość użytego przetwornika analogowo - cyfrowego wynosi 12 bit, co oznacza, że sygnał jest reprezentowany za pomocą 4096 różnych

poziomów napięcia. Przykładowy proces próbkowania sygnału dla wyprowadzeń

kanału I pokazano na Rysunku 2.16. Zastosowanie trybu różnicowego skutkuje

podwojeniem amplitudy sygnału, co wynika z pomiaru różnicy pomiędzy dwoma

wejściami przesuniętymi w fazie o 180 stopni. Ponadto, wbudowane przetworniki

mikrokontrolera Nucleo umożliwiają pracę w trybie synchronicznej konwersji dwóch przetworników ADC (ang. Dual Regular Simultaneous ADC Mode), co

umożliwia równoczesne przeprowadzanie konwersji przez oba przetworniki [16].

Jest to szczególnie korzystne, gdy chcemy jednocześnie mierzyć oba kanały radiowe

bez opóźnień sygnału w fazie.

Rysunek 2.16: Ilustracja procesu próbkowania sygnału.

Zgodnie z twierdzeniem Nyquista - Shannona, częstotliwość próbkowania musi

być co najmniej dwukrotnie większa niż najwyższa składowa częstotliwości sygnału próbkowanego [20]. Maksymalna częstotliwość graniczna widma odbieranego

sygnału przez układ CMX944 wynosi 25 kHz, zatem minimalna częstotliwość próbkowania zgodnie ze wzorem (2.3) będzie wynosić 50 kHz. Korzystnym

zabiegiem poprawiającym jakość przetwarzanego sygnału będzie wprowadzenie programowego nadpróbkowania (ang. Oversampling), wpłynie to zarówno na

stabilność pomiaru, jak i zwiększenie rozdzielczości. Używany mikrontroler oferuje

możliwość sprzętowego oversamplingu. Opcję tę skonfigurowano w taki sposób, aby sumować 16 próbek, a następnie dzielić przez 4 (równanie (2.4)), co pozwoli

zwiększyć rozdzielczość odbieranego sygnału do 14 bitów.

fs = 2 · B | (2.3)

gdzie:

fs - częstotliwość próbkowania

B - częstotliwość graniczna widma

s(t) = 1
4

X

16

i=1

s(ti

) | (2.4)

gdzie:
s(t) - wartość sygnału po nadpróbkowaniu

s(ti
- wartość sygnału po próbkowaniu

Takie rozwiązanie spowoduje zwiększenie częstotliwości próbkowania 16 -

krotnie, ponieważ sumujemy 16 próbek. Do precyzyjnego obliczenia częstotliwości

próbkowania, możemy wykorzystać układ licznika, który generuje przerwanie

układu ADC z każdym przepełnieniem licznika. Wartość przepełnienia obliczono za pomocą wzoru (2.5).

N =

fclock
16 · ftarget
− 1 | (2.5)

gdzie:
N - wartość przepełnienia licznika (Counter Period)

fclock - częstotliwość zegara taktującego mikrokontroler

ftarget - częstotliwość docelowa wywoływania przerwania

Przetwornik | cyfrowo | - | analogowy | DAC | pełni | funkcję | sterowania

częstotliwością zewnętrznego oscylatora lokalnego. Posiada on rozdzielczość 12

bitów i jest zdolny generować sygnał napięciowy w zakresie od 0 do 3.3 V.

Zastosowanie tego układu umożliwia dostosowanie zarówno stałej częstotliwości VCO jak i dokonywanie jej korekty (np. niwelowanie zjawiska efektu Dopplera).

Sposób połączenia przetworników mikrokontrolera z układem CMX944 pokazano

na Rysunku 2.17.

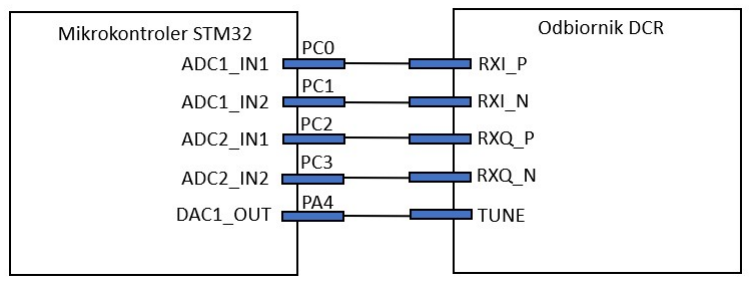
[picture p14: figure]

Rysunek 2.17: Schemat połączenia układów przetworników mikrokontrolera z układem CMX944.

### 2.3.3 Interfejs USB

Do przesyłania przetworzonych próbek radiowych do komputera wybrano

interfejs USB. W tym celu mikrokontroler STM32 został skonfigurowany jako urządzenie klasy CDC (ang. Communication Device Class). Taka konfiguracja

pozwala na stworzenie wirtualnego portu COM, co umożliwia emulację protokołu RS-232 [11]. Prędkość transmisji danych może wynosić 12 Mbit/s, i jest ona

wystarczająca w kontekście projektowanego urządzenia. Warto zaznaczyć, że na

magistralę USB musi być podany sygnał o częstotliwości 48 MHz, co wymaga odpowiedniej konfiguracji zegarów mikrokontrolera [11]. Zastosowany moduł

NUCLEO-L4676RG nie posiada wbudowanego złącza USB, dlatego zastosowano

zewnętrzny układ posiadający złącze Micro-USB 2.0, dodatkowo przez ten układ

poprowadzono zasilanie mikrontrolera poprzez wejście IN 5V. Schemat ideowy połączenia układów umieszczono poniżej (Rysunek 2.18):

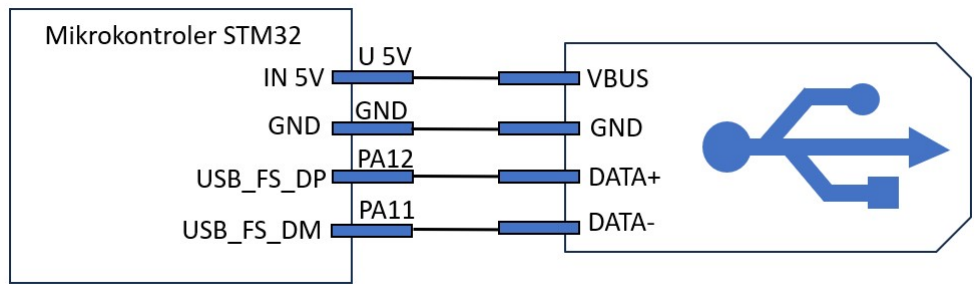
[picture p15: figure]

Rysunek 2.18: Schemat połączenia zewnętrznęgo złącza z wyprowadzeniami USB mikrokontrolera

### 2.3.4 Program sterujący

Podczas projektowania urządzenia stwierdzono, że do pełnego wykorzystania

wbudowanych układów mikrokontrolera, opisanych w powyższych sekcjach,

niezbędny jest dedykowany program. Jego głównym z zadaniem jest między

innymi:
- obsługa interejsu SPI
- konwersja przetworników ADC
- sterowanie napięciem LO
- obsługa intefejsu USB

W niniejszym podrozdziale przedstawiony został opis programu sterującego,

bazujący na ogólnym algorytmie przedstawionym na schemacie blokowym (Rysunek 2.19). Do napisania programu wykorzystano środowisko programistyczne

STM32CubeIDE | oferujące | możliwości | takie | jak | graficzna | konfiguracja

wewnętrznych układów oraz biblioteki wysokopoziome HAL. Oprogramowanie napisano w języku C ze względu na jego wydajność obliczeniową, przekładającą się

na szybkie wykonywanie poszczególnych bloków programowych.

Rysunek 2.19: Algorytm programu sterującego mikrontrolerem.

Na początku program aktywuje i konfiguruje wbudowane układy peryferyjne

mikrokontrolera. Mowa tutaj o interfejsie SPI, przetwornikach ADC i DAC oraz

komunikacji USB. Na tym etapie tworzone są również zmienne przechowujące

odpowiednie wartości rejestrów układu scalonego CMX944 oraz bufory do, których

przekazywane | są | przetworzone | próbki | odbieranego | sygnału | w | paśmie

podstawowym. Kolejnym etapem jest wgranie konfiguracji poprzez interfejs SPI.

Po zakończeniu transmisji program aktywuje układ przetwornika DAC podając

stałe napięcie na wyprowadzenie mikrontrolera oraz konwersję sygnału na wartość cyfrową (blok przetwornika ADC). Do ciągłego odczytu próbek z przetwornika

wykorzystano funkcję DMA (ang. Direct Memory Access). Zastosowano tutaj

technike podwójnego buforowania (ang. Double Buffering), która oznacza, że w

trakcie przetwarzania próbek należących do jednej połowy bufora, druga połowa

jest gotowa do odczytu. Operacja ta jest wykonywana naprzemiennie w celu

wypełnienia głównego bufora nadawczego. Próbki są gromadzone w postaci bloków sygnału trwających 100 ms (co przy częstotliwości 50 kHz, daje 5000 próbek na

jeden kanał IQ). Po wypełnieniu bufora następuje jego wysłanie poprzez interfejs

USB. Następnie zostaje on wyczyszczony, a operacja dodawania próbek powtarza

się ponownie.

## 3 Aplikacja komputerowa

Do prawidłowej interpretacji informacji zawartych w odbieranym sygnale

potrzebny jest dedykowany program. Powinien on umożliwiać akwizycje

przetworzonego sygnału satelitarnego oraz jego dekodowanie. Na tym etapie

projektowania założono, że najlepszym rozwiązaniem jest opracowanie łatwego w

obsłudze interfejsu graficznego zapewniającego wymienione funkcjonalności.

Wyjątkowo ważna jest tutaj wizualizacja odbieranych danych, umożliwiająca

użytkownikowi śledzenie sygnału w czasie rzeczywistym. Aby zapewnić prawidłowe

działanie całego systemu, program komputerowy powinien być wyposażony w

następujące moduły:
- odczyt próbek sygnału przez interfejs USB
- panel wizualizujący sygnał dla użytkownika
- zapis sygnału do pliku
- moduł przetwarzania/dekodowania sygnału

Dodatkowo, wymienione wyżej funkcje aplikacji, powinny działać niezależnie

w ramach jednego lub wielu procesów systemowych. W przeciwnym wypadku,

niemożliwa była by równoległa wizualizacja sygnału oraz jego zapis.

Program postanowiono napisać w języku Python na platformy docelowe takie

jak: Windows, Linux i mac0S. Język ten wybrano głownie z uwagi na szeroki

wybór dostępnych bibliotek ułatwiających zarówno komunikacje z portami

szeregowymi | komputera, | tworzenie | interfejsu | graficznego, | czy | też | samo

przetwarzanie sygnału radiowego. Jako środowisko programistyczne wybrano

edytor PyCharm.

W dalszych podrozdziałach przedstawiono działanie aplikacji, skupiając się na

analizie wykorzystanych modułów oraz ich strukturze programistycznej. Wybrane

rozwiązania zaprezentowano w oparciu o schematy blokowe, opisy użytych

algorytmów oraz ich parametry. Szczególną uwage poświęcono tutaj części

cyfrowego przetwarzania sygnału satelitaternego NOAA. Moduł ten stanowi

finalną funkcjonalność całego systemu, zaprojektowanego w perspektywie odbioru

sygnału, a następnie jego transformacji w obraz. W poniższych sekcjach

przedstawiono również praktyczne aspekty stworzonego interfejsu graficznego,

poprzez | umieszczenie | zdjęć | aplikacji | oraz | instrukcji | obsługi | do

zaimplementowanych funkcjonalności.

### 3.1 Ogólny opis programu

Aplikacje zrealizowano za pomocą technik programowania obiektowego.

Składa się ona z sześciu klas pokazanych na Rysunku 3.1. Każda klasa reprezentuje

odrębny moduł co pozwala uzyskać dobrą przejrzystość i czytelność kodu. Takie

podejście ułatwia także potencjalną rozbudowe programu o inne funkcjonalności.

Główną klasą jest klasa NOAA AP P, wykorzystująca metody zaimplementowane

w pozostałych klasach. Ponadto, zdefiniowano w niej również wygląd interfejsu

graficznego za pomocą biblioteki CustomT kinter, dostarczającej nowocześnie wyglądające i w pełni kongigurowalne widżety [15].

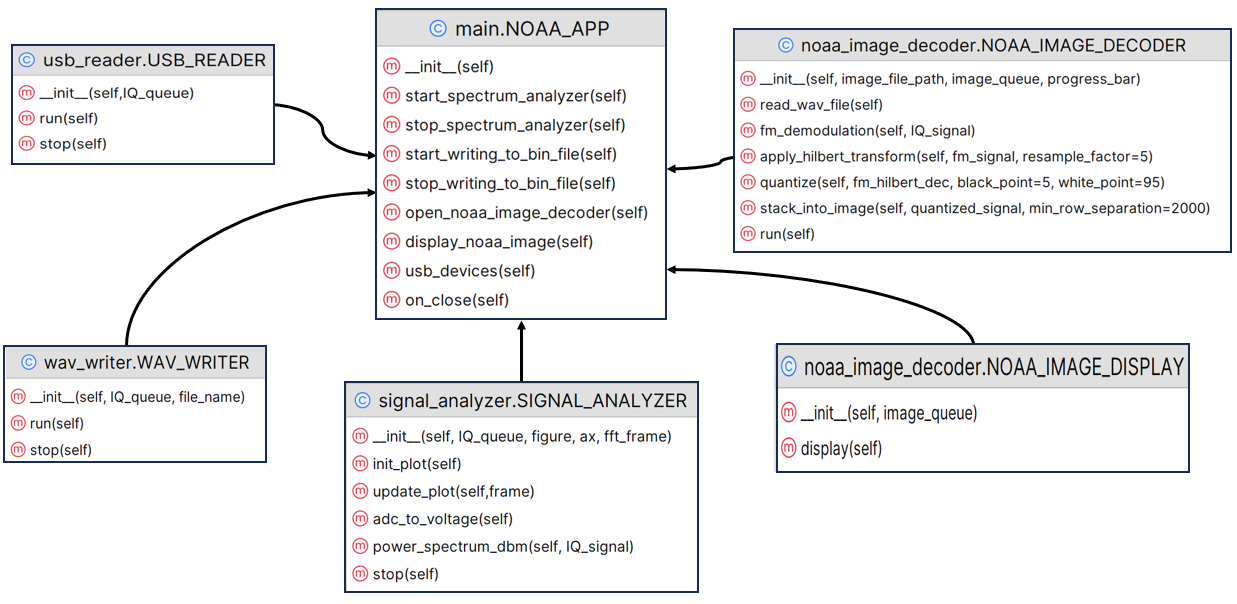
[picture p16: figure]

Rysunek 3.1: Diagram Klas napisanego programu.

Nazwy klas oraz odpowiadające im funkcje przedstawiono poniżej:
- USB READER - odczyt sygnału przez interfejs USB
- W AV W RIT ER - zapis sygnału do pliku .wav
- SIGNAL ANALY ZER - wizualizacja odbieranego sygnału
- NOAA IMAGE DECODER - przetwarzanie sygnału w obraz
- NOAA IMAGE DISP LAY - wyświetlanie obrazu

Problem równoległej pracy każdego z modułów rozwiązano za pomocą biblioteki

T hreading | pozwalającej | na | niezależne | działanie | wymienionych | bloków
programowych w obrębie jednego wątku [7]. Odczytane dane przez interfejs USB

przekazywano między klasami za pomocą tzw. kolejek (ang. Queue).

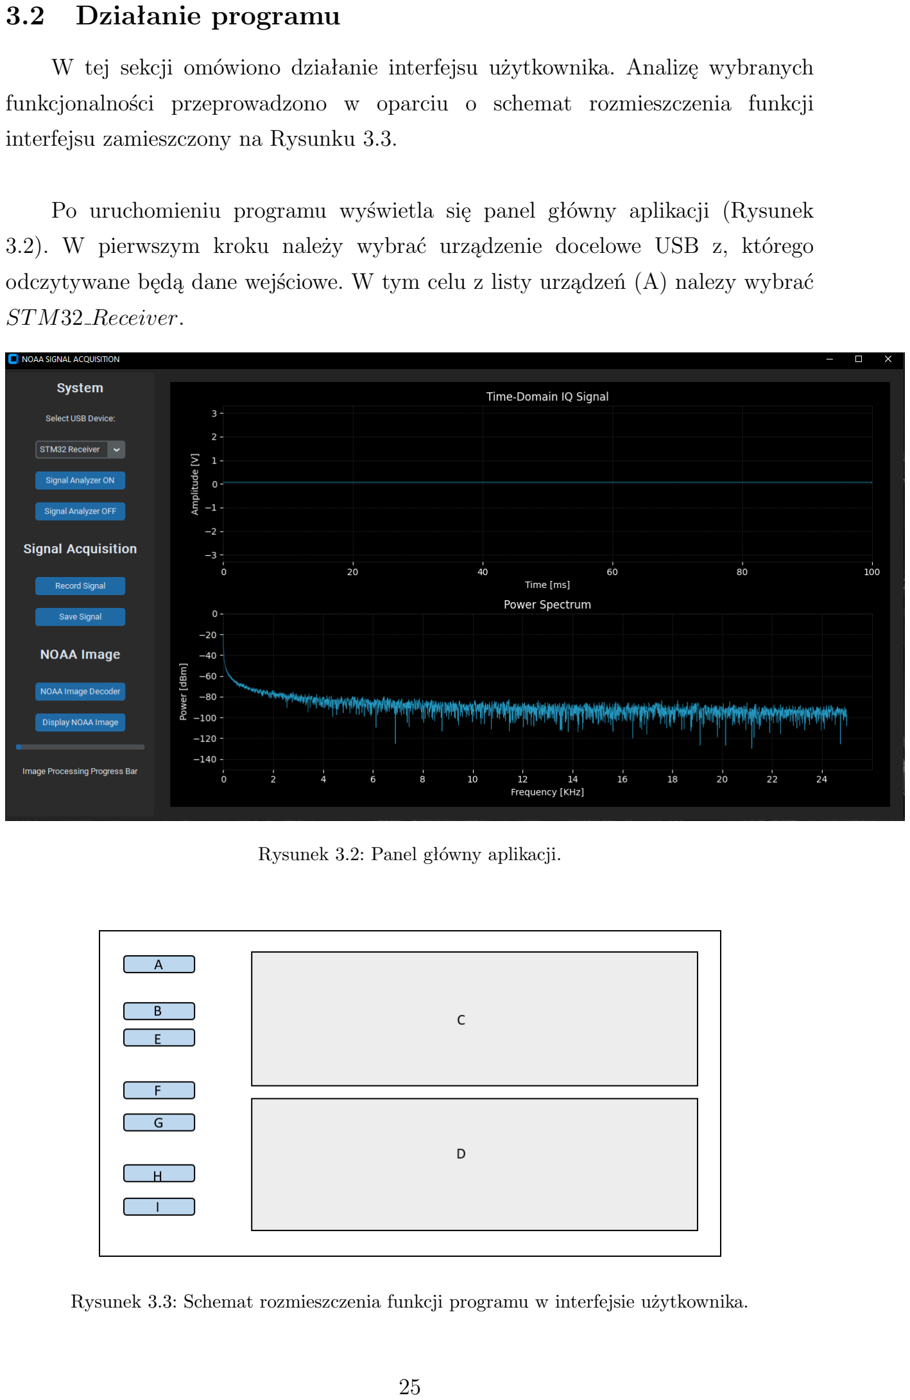
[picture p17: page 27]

### 3.2 Działanie programu

W tej sekcji omówiono działanie interfejsu użytkownika. Analizę wybranych

funkcjonalności przeprowadzono w oparciu o schemat rozmieszczenia funkcji

interfejsu zamieszczony na Rysunku 3.3.

Po uruchomieniu programu wyświetla się panel główny aplikacji (Rysunek

3.2). W pierwszym kroku należy wybrać urządzenie docelowe USB z, którego

odczytywane będą dane wejściowe. W tym celu z listy urządzeń (A) nalezy wybrać

STM32 Receiver.

Rysunek 3.2: Panel główny aplikacji.

Rysunek 3.3: Schemat rozmieszczenia funkcji programu w interfejsie użytkownika.

Jest to programowa nazwa zaprojektowanego urządzenia, i jednocześnie

zabezpieczenie przed odczytem z innego portu szeregowego. Przycisk B wyświetla dwa wykresy. Pierwszy z nich (C) pokazuje przebieg amplitudy sygnału w funkcji

czasu. Konwencja składowych IQ to alternatywny sposób reprezentowania

amplitudy i fazy, co prowadzi nas do liczb zespolonych. Reprezentacje sygnału zespolonego w dziedzinie czasu możemy zapisać zgodnie z wzorem (3.1) [12].

s(t) = I + j · Q | (3.1)

gdzie:
s(t) - sygnał w dziedzinie czasu

I - składowa synfazowa sygnału I

Q - składowa kwadraturowa sygnału Q

Amplitudę sygnału obliczono jako moduł liczby zespolonej zgodnie z wzorem (3.2).
A =

q
I
2 + Q² | (3.2)

gdzie:

A - amplituda sygnału

I - składowa synfazowa sygnału I

Q - składowa kwadraturowa sygnału Q

Sama analiza czasowa nie jest natomiast wystarczająca w celu poprawnej interpretacji odbieranych danych. Z tego powodu na drugim wykresie (D)

przedstawiono widmo mocy sygnału. Aby zobrazować przebieg w dziedzinie

częstotliwości, zastosowano znormalizowaną transformatę Fouriera względem skali decybelowej (dBm). W tym celu posłużono się wzorem (3.3) [8].

PdBm = 10 · log10

1000 ·

|F F T{s(t)}|²

R

!
(3.3)

gdzie:

PdBm - moc sygnału w dBm
F F T{s(t)} - szybka transformata Fouriera

R - nominalna rezystancja systemu (50 Ω)

Rozdzielczość widma zwiększono poprzez uzupełnienie sygnału zerami (ang.

Zero - Padding). Sygnał z mikrontrolera przesyłano w postaci bloków o długości

5000 próbek (patrz: sekcja 2.3.4), które przed obliczeniem FFT uzupełniano zerami do najbliższej potęgi liczby 2, czyli 8192. W celu zniwelowania zjawiska wycieku

widma, czyli błędów wynikających z przetwarzania sygnału o niepełnym okresie, zastosowano okno Hamminga (Rysunek 3.4). Zaletą tego okna jest stopniowe

tłumienie amplitudy na jego krańcach. Prowadzi to do większej dokładności

pomiarów i łatwiejszej interpretacji wyników. Funkcję okna zastosowano na sygnale w dziedzinie czasu, za pomocą wzoru (3.4).

s(t)w = s(t) · w(n) | (3.4)

gdzie:
s(t)w - sygnał wymnożony przez okno

s(t) - sygnał w dziedzinie czasu

w(n) - funkcja okna Hamminga

Rysunek 3.4: Wykres przedstawiający okno Hamminga.

Opisana funkcjonalność pełni role prostego analizotora widma, umożliwiającego

śledzenie sygnału w czasie rzeczywistym. Wyłączenie modułu odbywa sie za pomocą

przycisku E.

Przycisk F służy do rozpoczęcia zapisu aktualnie wyświetlanego sygnału do pliku z rozszerzeniem .wav (ang. Waveform Audio File Format). Jest to format

plików | dźwiękowych, | który | nie | stosuje | kompresji | bitów, | umożliwiając

przechowywanie nagrań audio o parametrach takich jak: częstotliwość próbkowania oraz ilość kanałów [3]. Za pomocą przycisku G proces zapisywania zostaje

zakończony.
Ostatnie dwa przyciski (H, I), służą kolejno do przetworzenia sygnału na

obraz oraz do jego wyświetlenia. Zaimplemetowany moduł dekodera obrazu działa

w trybie offline, tzn. przetwarza wybrany przez użytkownika plik .wav.

Szczegółowy opis modułu wraz z obsługą emitowanego protokołu przez satelity

NOAA zamieszczono w następnym podrozdziale.

### 3.3 Dekoder obrazu

W niniejszym podrozdziale skupiono się na omówieniu sygnału nadawawanego

przez satelity NOAA. Pierwszą sekcję poświecono na dostarczenie istotnych

informacji na temat protokołu zaimplementowanego w sygnale satelitarnym. Druga

sekcja zawiera opis procesu dekodowania oraz jego programowową implementacje

wraz z prezentacją uzyskanych wyników.

### 3.3.1 Protokół APT

Satelity pogodowe NOAA wykorzystują protokół Automatycznej Transmisji obrazu (ang. Automatic Picture Transmission). Sygnał jest nadawany z

wykorzystaniem modulacji ciągłej FM (ang. Frequency Modulation). Nie jest on

dodatkowo kodowany przez co jest ogólnodostępny dla odbiorców[1]. Przesyłane

dane obejmują:
- dwa kanały obrazowe
- informacje o telemetrii
- sekwencje synchronizujące

Obrazy są przesyłane w dwóch kanałach, z których jeden obejmuje zakres widzialny, a drugi podczerwień (Rysunek 3.3.1). Dane dla obu kanałów są

przesyłane jako pozioma linia skanu o długości 2080 pikseli [1].

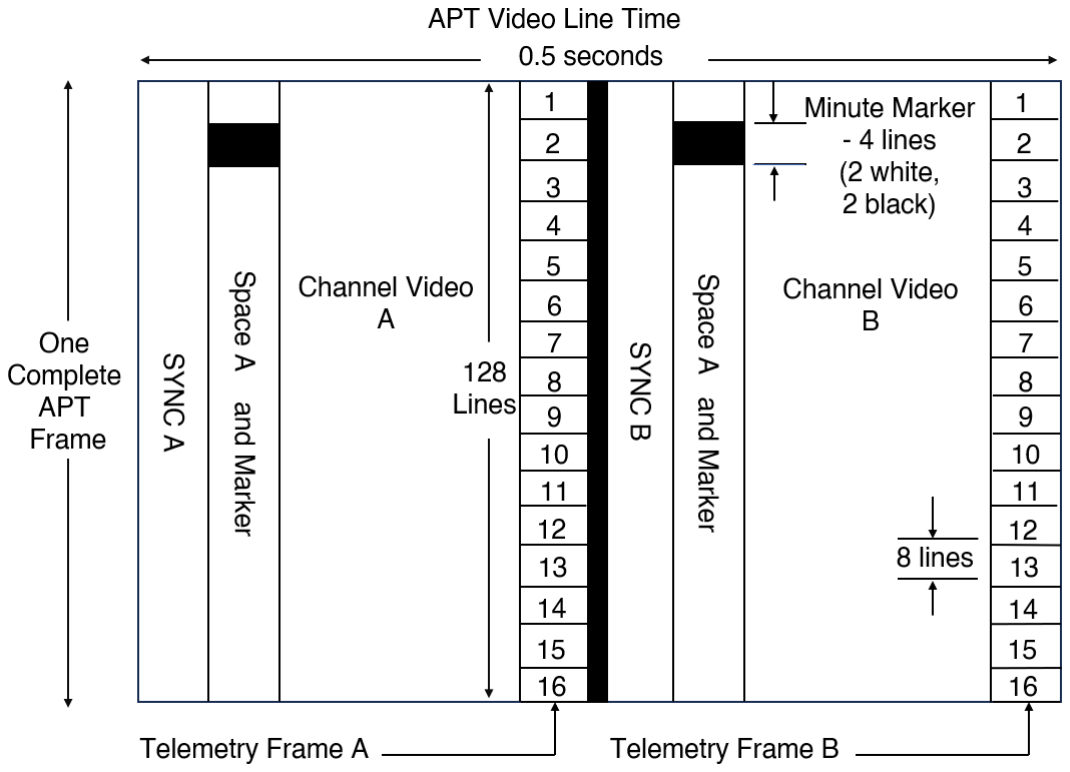
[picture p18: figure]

Rysunek 3.5: Kompletna ramka protokołu APT [1].

Każdy obraz wykorzystuje 909 pikseli, natomiast reszta przeznaczona jest na telemetrię i synchronizację. Linie transmitowane są w tempie dwóch na sekunde [1].

Sekcja telemetryczna składa się z szesnastu bloków o długości ośmiu linii

każdy. Służą one jako odniesienie w celu dekodowania kanałów obrazu. Dane

synchronizacyjne są transmitowane na początku każdego kanału wideo,

umożliwiając dostosowanie częstotliwości próbkowania przez urządzenie odbiorcze.

Zawierają one znaczniki czasu, składające się z czterech lini powtarząjących się co 60 sekund [1].

Transmitowany sygnał jest podnośną zakodowaną na 256 poziomach amplitudy za pomocą modulacji AM (ang. Amplitude Modulation), która następnie

jest modulowana częstotliwościowio (FM) na nośnej o częstotliwości 137 MHz[1].

Szerokość pasma radiowego wynosi około 34 kHz, jednakże pełne pasmo sygnału

nie jest niezbędne do uzyskania obrazu. Mniejsza szerokość odbieranego widma

może natomiast skutkować pogorszeniem jakości przesyłanego zdjęcia.

### 3.3.2 Algorytm przetwarzania obrazu

Proces dekodowania sygnału w obraz zrealizowano w oparciu o schemat

ogólny algorytmu zamieszczony na Rysunku 3.7. Wyniki programu zaprezentowano

w oparciu o dostępne w internecie nagranie sygnału satelitarnego NOAA. W

pierwszej kolejności sygnał poddano demodulacji FM. W tym celu zastosowano tzw. polarny dyskryminator częstotliwości (Rysunek 3.6). Wykorzystuje on kolejne

próbki sygnału FM, a następnie wymnaża przez sprzężenie poprzedniej próbki. Z

usyskanej wartości zespolonej następnie obliczany jest kąt co wynikowo daje chwilową wartość częstotliwości [2].

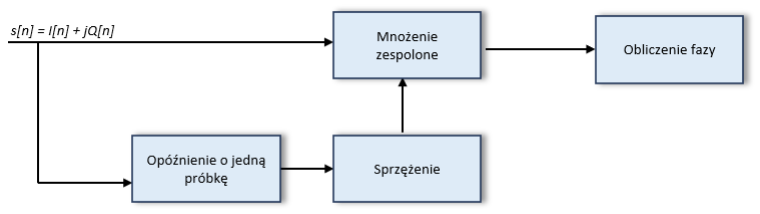
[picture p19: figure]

Rysunek 3.6: Schemat blokowy dyskryminatora częstotliwości.

W kolejnym etapie, wyodrębnia się informacje zakodowane na podnośnej AM.

Aby to osiągnąć, konieczne jest uzyskanie amplitudowej obwiedni sygnału (Rysunek 3.8). Operacje tą wykonano za pomocą filtru Hilberta, który pełni rolę

90 - stopniowego przesuwnika fazowego [20].

Rysunek 3.7: Schemat blokowy algorytmu dekodowania obrazu.

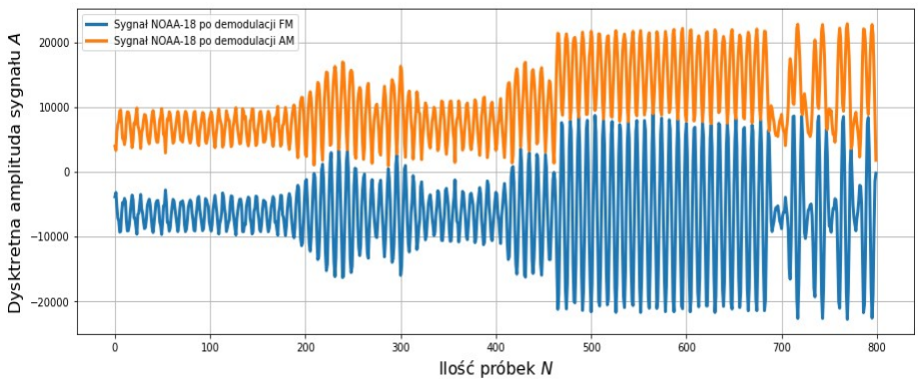
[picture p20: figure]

Rysunek 3.8: Obwiednia sygnału FM po transformacji Hilberta.

Z analizy zawartej w podrozdziale 3.3.1 wynika że zdjęcie zostało zakodowane

na 256 poziomach amplitudy, w związku z tym konieczne jest przeprowadzenie

kwantyzacji uzyskanej obwiedni do wartości 8 bitów. Na tym etapie proces

dekodowania sygnału zostaje zakończony.

W celu ekstrakcji linii obrazowych, należy wykorzystać przesyłane w ramce protokołu APT (Rysunek 3.5) dane synchronizujące. Strukturę sekwencji S w oparciu o informacje zamieszczone w opisie protokołu [1], pokazano poniżej:

S =

0 0 255 255 0 0 255 255

0 0 255 255 0 0 255 255

0 0 255 255 0 0 255 255

0 0 255 255 0 0 | 0 | 0
0 0 | 0

Szukanie tej sekwencji polega na przeprowadzeniu korelacji z iterowanym sygnałem. Po jej sukcesywnym znalezieniu (duża wartość korelacji) przesyłana

linia wideo jest dodawana do tablicy przechowującej cyfrowe dane obrazowe.

Poniżej przedstawiono uzyskany za pomocą stworzonego algorytmu obraz (Rysunek 3.9), którego lewa strona reprezentuje kanał widzialny, a prawa kanał

podczerwony.

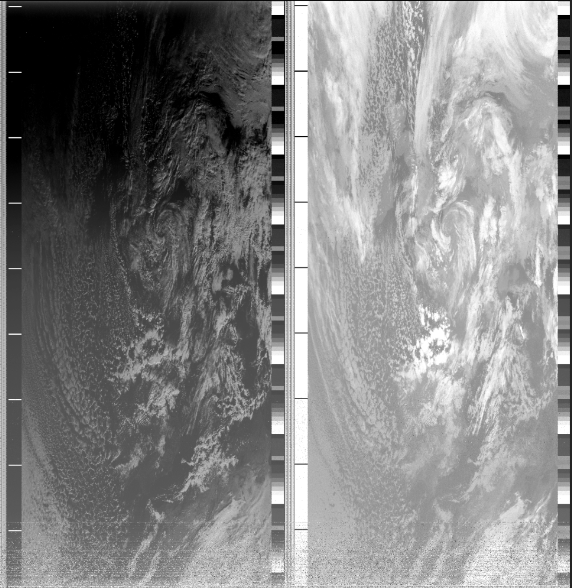
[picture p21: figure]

Rysunek 3.9: Zdjęcie uzyskane w procesie przetwarzania sygnału sateliternego NOAA.

## 4 Badania i testy

W celu potwierdzienia poprawności działania zaprojektowanego urządzenia i

oprogramowania z punktu widzenia założonych wymagań, przeprowadzono testy

prototypu. Z analizy zawartej w sekcji 3.3.1 wynika, że zaprojektowany system

akwizycji danych radiowych powinien umożliwiać odbiór sygnałów o częstotliwości 137 MHz, zakodowanych za pomocą modulacji częstotliwości (FM). Najlepszym

rozwiązaniem byłoby przeprowadzenie testów terenowych. Jednakże, z uwagi na

brak odpowiednio zaprojektowanej anteny, zdecydowano się na przeprowadzenie

pomiarów laboratoryjnych, które dodatkowo pozwalają na precyzyjne wyznaczenie

parametrów radioodbiornika.

W tym rozdziale omówiono metody pomiarowe, które zostały wykorzystane do

zbadania zaprojektowanego urządzenia. Ponadto przedstawiono uzyskane wyniki,

obejmujące charakterystyki oraz kluczowe parametry odbiornika.

### 4.1 Układ pomiarowy

Do realizacji pomiarów posłużono się poniższym zestawem aparatury kontrolno-

pomiarowej:
- Generator | sygnałów | RF | SMC100A | marki | Rohde&Schwarz; | zakres
częstotliwości: | 9 | kHz | - | 3.2 | GHz; | tryby | modulacji | analogowej
( AM/FM/ φM/pulse modulation); błąd poziomu poniżej 9 dB; szum fazowy

SSB na poziomie –111 dBc
- Laptop firmy ASUS; procesor: Intel(R) Core(TM) i5-7300HQ CPU 2.5 GHZ;

pamięć RAM: 8 GB; procesor graficzny NVIDIA GeForce GTX 1050
Obwód wykorzystany do badań (Rysunek. 4.1) przedstawiono na rysunku

poniżej:

Rysunek 4.1: Schemat układu pomiarowego do wyznaczania parametrów zaprojektowanego urządzenia oraz weryfikacji wskazań oprogramowania.

### 4.2 Pomiary

W pierwszej fazie testów przeprowadzono analizę widmową sygnału. Pomiary

te polegały na pomiarze sygnału z generatora RF za pomocą zaprojektowanego

radioodbiornika. Następnie sygnał, sprowadzony do pasma podstawowego, został

przedstawiony graficznie za pomocą skryptu napisanego w języku Python. W tym

celu użyto obwodu pomiarowego zamieszczonego na Rysunku 4.1. Parametry

skryptu, służącego do przedstawienia widma, zawarto w poniższej tabeli:

Parametr | Wartość
częstotliwość próbkowania | 60 KHz
liczba próbek widma | 8192
zasotosowana funkcja okna | Hamming

Tabela 4.1: Parametry programu graficznej reprezentacji widma.

Analiza widmowa została przeprowadzona w dwóch etapach. W pierwszym z

nich dokonano pomiaru sygnału o stałej dewiacji częstotliwości, przy jednoczesnej zmianie poziomu mocy sygnału wejściowego (Rysunek 4.2 - 4.4). Pomiary wykonano

dla trzech rożnych poziomów mocy i częstotliwości generowanego sygnału LO równej 137.016 MHz (wartość ta odpowiada częstotliwości nadawania satelity NOAA-15).

Ustawienia generatora podano w tabeli poniżej:

Parametr | Wartość
Częstliwość sygnału radiowego | 137.016 MHz
moc sygnału wejściowego | -90, -100, -110 dBm
tryb modulacji | FM
dewiacja częstotliwości | 2 kHz

Tabela 4.2: Parametry generatora sygnałów radiowych - parametry użyte do weryfikacji odpowiedzi częstotliwościowej układu.

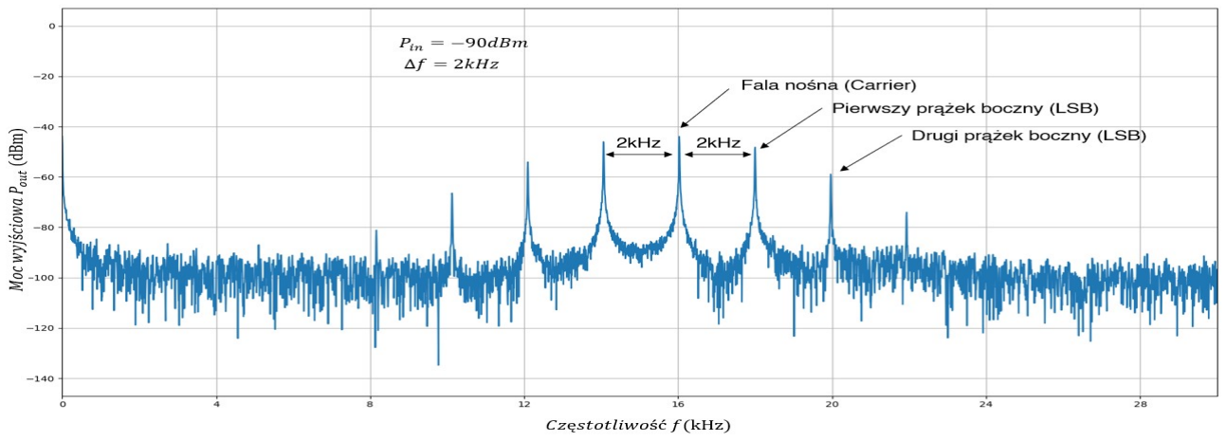
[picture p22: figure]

Rysunek 4.2: Widmo sygnału FM o mocy -90 dBm i dewiacji częstotliwośći 2 kHz.

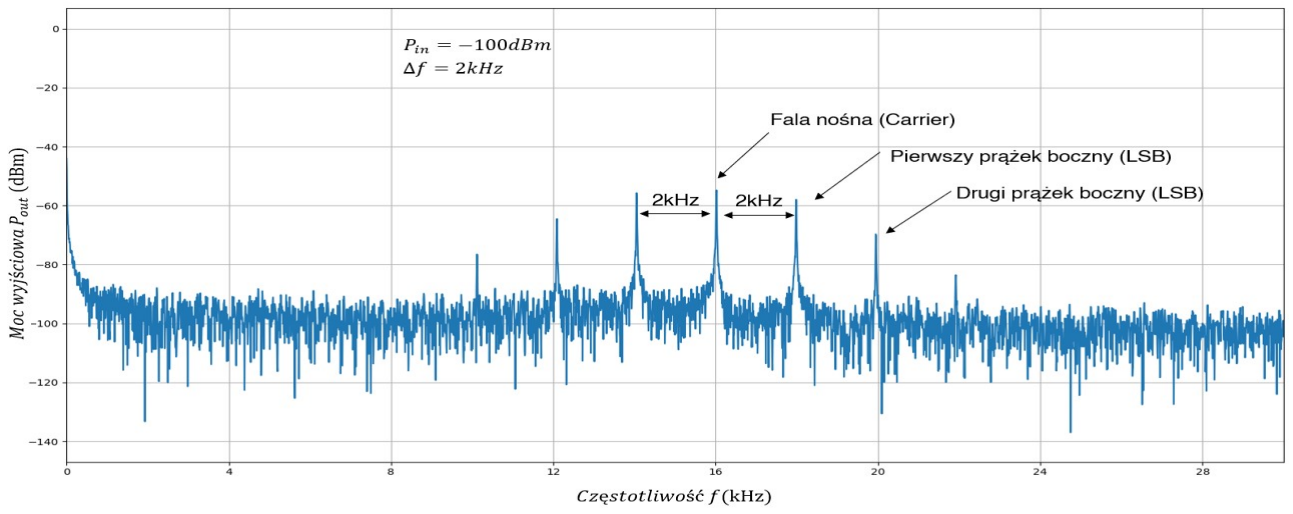
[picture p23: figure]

Rysunek 4.3: Widmo sygnału FM o mocy -100 dBm i dewiacji częstotliwośći 2kHz.

Rysunek 4.4: Widmo sygnału FM o mocy -110 dBm i dewiacji częstotliwośći 2kHz.

Z widm przedstawionych na Rysunkach 4.2 - 4.4, można zaobserwować prążek

występujący na częstotliwości 16 kHz, jest to poprawne z uwagi na fakt, że sygnał

nośnej generowany przez układ LO był przesunięty o 16 kHz. Charakterystyczne

prążki boczne dla modulacji FM widoczne są w odległości 2 kHz zarówno

względem siebie, jak i od nośnej, co jest zgodne z dewiacją częstotliwości

wynoszącą 2 kHz. Wraz ze spadkiem mocy sygnału wejściowego, obserwujemy

spadek amplitudy mocy odbieranego sygnału, natomiast nawet dla wartości -110

dBm informacje zawarte w sygnale są w dalszym ciągu użyteczne.

W następnym etapie dokonano pomiaru sygnału o stałej mocy wejściowej, z zastosowaniem różnych wartości dewiacji częstotliwości (Rysunek 4.5 - 4.7).

Częstotliwość | generowanego | sygnału | przez | oscylator | lokalny | pozostała

niezmieniona. Parametry generatora dla tej części pomiarów przedstawiono w

tabeli 4.3.

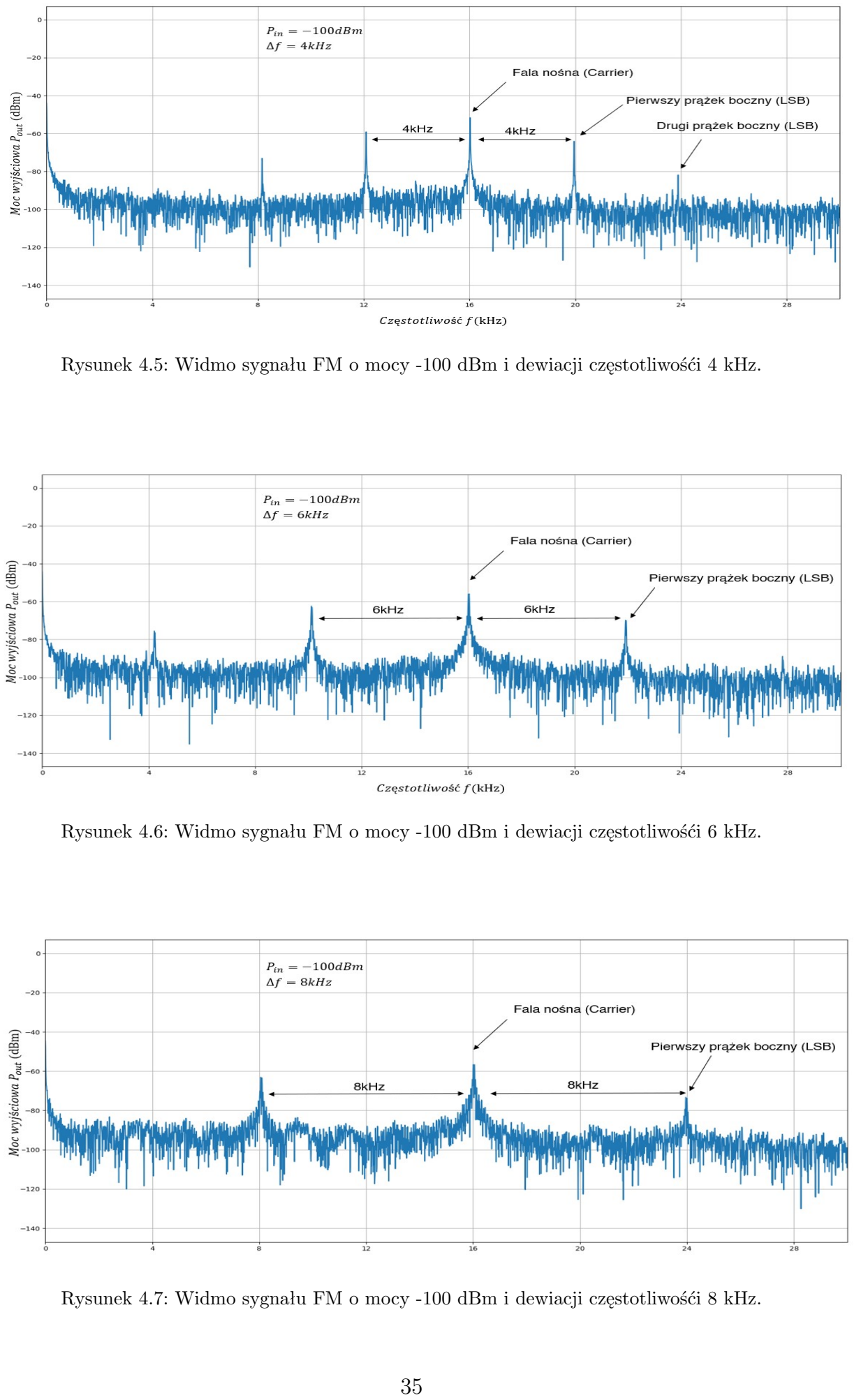
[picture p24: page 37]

Rysunek 4.5: Widmo sygnału FM o mocy -100 dBm i dewiacji częstotliwośći 4 kHz.

Rysunek 4.6: Widmo sygnału FM o mocy -100 dBm i dewiacji częstotliwośći 6 kHz.

Rysunek 4.7: Widmo sygnału FM o mocy -100 dBm i dewiacji częstotliwośći 8 kHz.

Parametr | Wartość
częstotliwość fali nośnej | 137.016 MHz
moc sygnału wejściowego | -100 dBm
tryb modulacji | FM
dewiacja częstotliwości | 4, 6, 8 kHz

Tabela 4.3: Parametry generatora sygnałów radiowych - obserwacja widma podczas zmiany dewiacji częstotliwości.

Z załączonych przebiegów wynika że urządzenie poprawnie interpretuje

zmienne wartości dewiacji częstotliwości. Prążki boczne modulacji FM pokrywaja

się z ustawieniami generatora.

Na koniec przeprowadzono pomiary czułości użytkowej odbiornika. W

generatorze przełączono tryb modulacji z FM na AM. W celu pomiaru czułości,

zdecydowano się programowo mierzyć stosunek mocy użytecznego prążka

modulacji AM do poziomu szumu. W ten sposób obliczono wartość parametru SNR (ang. Signal to Noise Ratio) zgodnie ze wzorem (4.1). Następnie, moc

sygnału wejściowego stopniowo obniżano, aż do osiągnięcia SNR o wartości 10 dB.

SNR = 10 · log10

Ps
Pn
(4.1)

gdzie:

SNR - stosunek sygnału do szumu wyrażony w dB

Ps - moc sygnału

Pn - moc szumu

Czułość zaprojektowanego urządzenia wyniosła -114 dBm, co odpowiada wartości

napięcia sygnału wejściowego równej 0.4462 µV.

## 5 Podsumowanie

Celem niniejszej pracy inżynierskiej było zaprojektowanie i praktyczna

realizacja systemu akwizycji danych z satelit meteorologicznych NOAA. Projekt

obejmował zaprojektowanie odbiornika radiowego definiowanego programowo oraz

stworzenie aplikacji umożliwiającej tworzenie map pogodowych na podstawie

odebranego sygnału. Urządzenie miało mieć zdolność odbioru sygnałów FM o

częstotliwości około 137 MHz, a oprogramowanie miało dekodować sygnał w celu

przetworzenia go na obraz. Na podstawie uzyskanych wyników oraz obserwacji

można stwierdzić, że cel został osiągnięty. Jednakże z powodu braku odpowiedniej

anteny oraz czasu, aby przeprowadzić testy terenowe, wykonano jedynie badania w

warunkach laboratoryjnych z użyciem specjalistycznego sprzętu pomiarowego.

Przeprowadzona w labolatorium analiza częstotliwościowa sygnału, świadczy o

prawidłowej pracy urządzenia. Zmierzono również czułość użytkową odbiornika,

która wyniosła -114 dBm. Wartość ta jest wystarczająca jeśli chodzi o odbiór

sygnału pochodzącego z satelit NOAA. Poszczególne bloki programowe,

zaimplementowane | zarówno | w | układzie | mikrokontrolera | jak | i | aplikacji

komputerowej wielokrotnie modyfikowano i korygowano, aby zapewnić ich

prawidłowe działanie. Poprawność modułu oprogramowania, który odpowiada za

dekodowanie odbieranych danych i przekształcenie ich w obraz, została

zweryfikowana przy użyciu ogólnodostępnego nagrania sygnału pochodzącego z

satelity NOAA-18.

Aby w pełni wykorzystać potencjał zbudowanego urządzenia, w przyszłości należy zaprojektować antenę pracującą w paśmie VHF (ang. Very High Frequency)

o odpowiednio dużym zysku energetycznym. Dodatkowo, zaprojektowany układ

odbiornika DCR powinien być rozbudowany o pętle fazową z uwagi na występującą

dewiacje częstotliwości zewnętrznego VCO. Nie mniej ważne jest również

wprowadzenie korekty zapewniającej zniwelowanie efektu Dopplera. Testy

przeprowadzono w oparciu o stałą częstotliwość generowaną przez układ LO.

Potencjalnym rozwiązaniem problemu byłaby programowa korekta podawanego

napięcią w zależności od odpowiedniego algorytmu sterującego. Finalnym krokiem

byłoby pełne zintegrowanie zaprojektowanego układu z mikrontrolerem STM32 na jednej płytce drukowanej PCB (ang. Printed Circuit Board), co rozwiązałoby

napotkane problemy związane z integralnością sygnałową.

## Spis rysunków

2.1 Schemat blokowy projektowanego urządzenia typu SDR | | 3
2.2 Schemat blokowy układu scalonego CMX994 [14] | | 4
2.3 Blok przemiany częstotliwości układu scalonego CMX994 [14] | | 6

2.4 Charakterystyki amplitudowo – częstotliwościowe filtru w zależności
od konfiguracji współczynnika skalującego [14] | 7

2.5 Układ oscylatora lokalnego składającego się z generatora VCO -

MAX2607 oraz szerokopasmowego wzmacniacza ADL5611 | 9
2.6 Charakterystyka parametru S21 układu ADL5611 | 10
2.7 Schemat Pomiarowy układu oscylatora lokalnego | 11

2.8 Charakterystyka przedstawiająca zależność między częstotliwością

sygnału generowanego przez układ MAX2607, a napięciem

sterującym VT UNE | 11

2.9 Charakterystyka mocy wyjściowej w funkcji napięcia sterującego

układu LO ze wzmacniaczem ADL5611 | 11

2.10 Wzmacniacz niskoszumny odbiornika scalonego CMX994 oraz układ
dopasowania anteny [14] | 12
2.11 Charakterystyka | amplitudowo-czestotliwościowa | współczynnika
odbicia S11 | 13
2.12 Charakterystyka | Amplitudowo-Czestotliwościowa | współczynnika
transmisji S21 | 14
2.13 Schemat lini zasilających układu scalonego CMX944 | 16
2.14 Zdjęcie płyty deweloperskiej Nucleo z noty katalogowej urządzenia [17]. 17

2.15 Schemat połączenia układu SPI mikrokontrolera z interfejsem C-BUS

układu CMX944 | 18
2.16 Ilustracja procesu próbkowania sygnału | 19

2.17 Schemat połączenia układów przetworników mikrokontrolera z

układem CMX944 | 20

2.18 Schemat połączenia zewnętrznęgo złącza z wyprowadzeniami USB

mikrokontrolera | 21
2.19 Algorytm programu sterującego mikrontrolerem | 22
3.1 Diagram Klas napisanego programu | 24
3.2 Panel główny aplikacji | 25

3.3 Schemat rozmieszczenia funkcji programu w interfejsie użytkownika. . 25

3.4 Wykres przedstawiający okno Hamminga | 27
3.5 Kompletna ramka protokołu APT [1] | 28
3.6 Schemat blokowy dyskryminatora częstotliwości | 29

3.7 Schemat blokowy algorytmu dekodowania obrazu | 30
3.8 Obwiednia sygnału FM po transformacji Hilberta | 30

3.9 Zdjęcie uzyskane w procesie przetwarzania sygnału sateliternego NOAA. 31

4.1 Schemat | układu | pomiarowego | do | wyznaczania | parametrów
zaprojektowanego | urządzenia | oraz | weryfikacji | wskazań
oprogramowania | 32
4.2 Widmo sygnału FM o mocy -90 dBm i dewiacji częstotliwośći 2 kHz. | 33
4.3 Widmo sygnału FM o mocy -100 dBm i dewiacji częstotliwośći 2kHz. | 34
4.4 Widmo sygnału FM o mocy -110 dBm i dewiacji częstotliwośći 2kHz. | 34

4.5 Widmo sygnału FM o mocy -100 dBm i dewiacji częstotliwośći 4 kHz. 35

4.6 Widmo sygnału FM o mocy -100 dBm i dewiacji częstotliwośći 6 kHz. 35

4.7 Widmo sygnału FM o mocy -100 dBm i dewiacji częstotliwośći 8 kHz. 35

## Spis tabel

2.1 Rejestr General Control Układu Scalonego CMX944 [14] | | 5
2.2 Rejestr Rx Control Układu Scalonego CMX944 [14] | | 5

2.3 Współczynnik skalujący w zależności od konfiguracji bitów 3 - 4

rejestru Rx Control | 7

2.4 Zakres częstotliwości w zależności od konfiguracji bitów 5 - 6 rejestru

General Control | 8

2.5 Dzielnik częstotliwości w zależności od konfiguracji bitów 1-2 rejestru

RX Control | 9
2.6 Rejestr RX Gain Układu Scalonego CMX944 [14] | 12

2.7 Wzmocnienie układu LNA w zależności od konfiguracji bitów 6 - 7

rejestru Rx Gain | 13

2.8 Wzmocnienie układu LNA w zależności od konfiguracji bitów 4 - 5

rejestru Rx Gain | 13

2.9 Wzmocnienie układu VGA w zależności od konfiguracji bitów 0 - 2

rejestru Rx Gain | 14

2.10 Zestawienie napięć i prądów zasilania wykorzystanych układów

scalonych | 15
2.11 Parametry transmisji mikrokontrolera | 18
4.1 Parametry programu graficznej reprezentacji widma | 33

4.2 Parametry generatora sygnałów radiowych - parametry użyte do

weryfikacji odpowiedzi częstotliwościowej układu | 33

4.3 Parametry generatora sygnałów radiowych - obserwacja widma

podczas zmiany dewiacji częstotliwości | 36

## Literatura

[1] ”Automatic Picture Transmission (APT)”. https://www.sigidwiki.com/

wiki/Automatic_Picture_Transmission_(APT). (https://www.sigidwiki.com/wiki/Automatic_Picture_Transmission_(APT))

[2] ”Lab 1: Working with IQ data in Python”. https://witestlab.poly.edu/

~ffund/el9043/labs/lab1.html. (https://witestlab.poly.edu/~ffund/el9043/labs/lab1.html)

[3] ”What is a WAV file?”. https://docs.fileformat.com/audio/wav//.
[4] M. Haridim A. Luzzatto. ”Wireless Transceiver Design”. Wiley, 2017.
[5] A. Ciołkosz. ”Teledetekcja satelitarna źródłem informacji o obiektach,

zjawiskach i procesach zachodzących na Ziemi”. Polska Akademia Nauk, 2005.

[6] ANALOG DEVICES. ”30 MHz to 6 GHz RF/IF Gain Block”. D11508-0-

12/15(B), December 2015.

[7] Python Software Foundation. ”threading — Thread-based parallelism”. https:

//docs.python.org/3/library/threading.html.

[8] S. Hilbert. ”Power Spectrum in MATLAB”. https://www.bitweenie.com/

listings/power-spectrum-matlab/. (https://www.bitweenie.com/listings/power-spectrum-matlab/)

[9] Maxim Integrated. 45MHz to 650MHz, Integrated IF VCOs with Differential

Output. 19-1673, April 2002.

[10] K. Paprocki. ”Mikrokontrolery STM32 w praktyce”. BTC, 2009.
[11] B. Kurosz. ”Kurs STM32 F4 – 11 – Komunikacja przez USB”. https://

forbot.pl/blog/kurs-stm32-f4-11-komunikacja-przez-usb-id13477.

[12] M. Lichtman. ”PySDR: A Guide to SDR and DSP using Python”. https:

//pysdr.org/content/sampling.html.

[13] Data National Environmental Satellite and Information Service. https://www.

nesdis.noaa.gov/current-satellite-missions/currently-flying.

[14] CML Microcircuits Plc. ’CMX994/CMX994A/CMX994E/CMX994G Direct

Conversion Receivers’. D/994 A E/1, September 2015.

[15] T. Schimansky. | ”CustomTkinter A modern and customizable python UI-
library based on Tkinter”. | https://customtkinter-tomschimansky-com.

translate.goog/?_x_tr_sl=en&_x_tr_tl=pl&_x_tr_hl=pl&_x_tr_pto=sc. (https://customtkinter-tomschimansky-com.translate.goog/?_x_tr_sl=en&_x_tr_tl=pl&_x_tr_hl=pl&_x_tr_pto=sc)

[16] STMicroelectronics. ”STM32’s ADC modes and their applications”. 16840,

March 2010.

[17] STMicroelectronics. ”STM32 Nucleo-64 boards (MB1136)”. UM1724, August

2020.

[18] P. Struzik. ”Satelity meteorologiczne od 40 lat w służbie Instytutu Meteorologii

i Gospodarki Wodnej”. Polska Akademia Nauk, 2008.

[19] T. F Collins, R.Getz, D. Pu, A. M. Wyglinski. ”Software-Defined Radio for

Engineers”. Artech House Publishers, 2018.

[20] T.P. Zieliński. ”Cyfrowe przetwarzanie sygnałów od teorii do zastosowań”.

Wydawnictwa Komunikacji i Łączności Warszawa, 2005.

[21] J. Ziembicki. ”Dławiki w obwodach zasilania”. https://ep.com.pl/rynek/

wybor-konstruktora/14535-dlawiki-w-obwodach-zasilania. (https://ep.com.pl/rynek/wybor-konstruktora/14535-dlawiki-w-obwodach-zasilania)

## Załącznik 1 - Schemat elektryczny odbiornika DCR

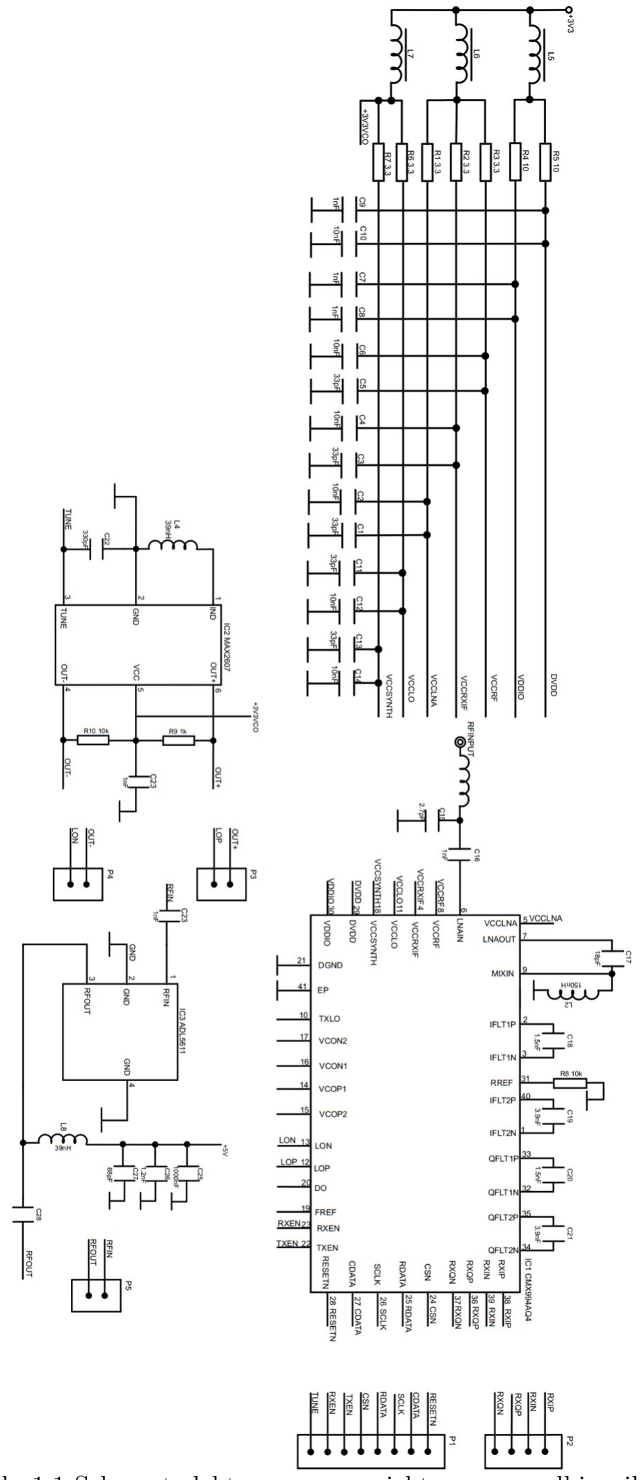
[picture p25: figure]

Rysunek. 1.1 Schemat elektryczny zaprojektowanego odbiornika DCR.

## Załącznik 2 - Schemat ideowy odbiornika SDR

Rysunek. 2.1 Schemat ideowy połączenia odbiornika DCR z mikrokontrolerem.

## Załącznik 3 - Obwody drukowane oraz zdjęcia

## projektu

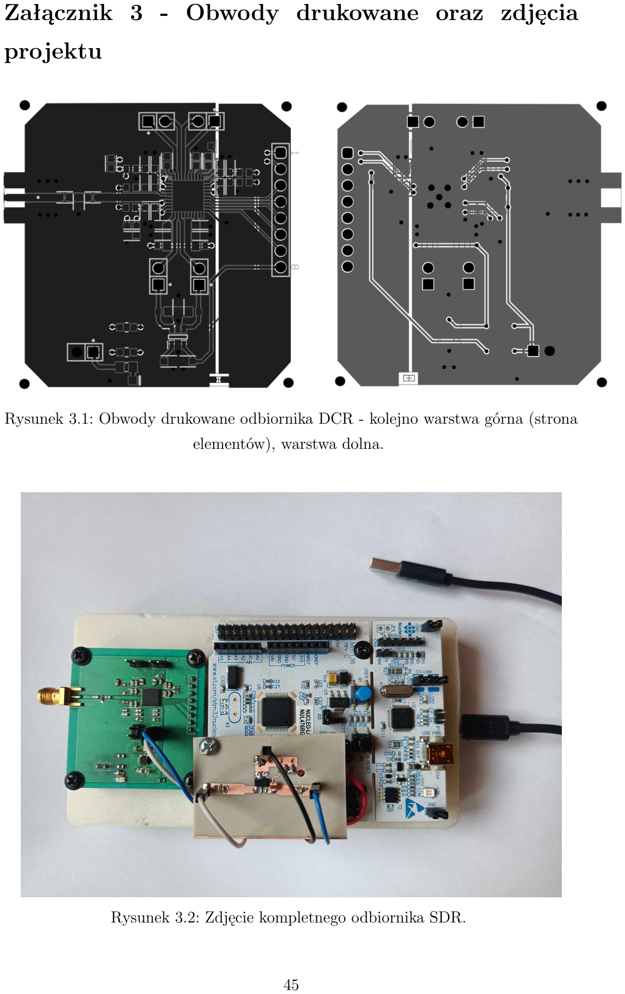
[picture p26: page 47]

Rysunek 3.1: Obwody drukowane odbiornika DCR - kolejno warstwa górna (strona

elementów), warstwa dolna.

Rysunek 3.2: Zdjęcie kompletnego odbiornika SDR.

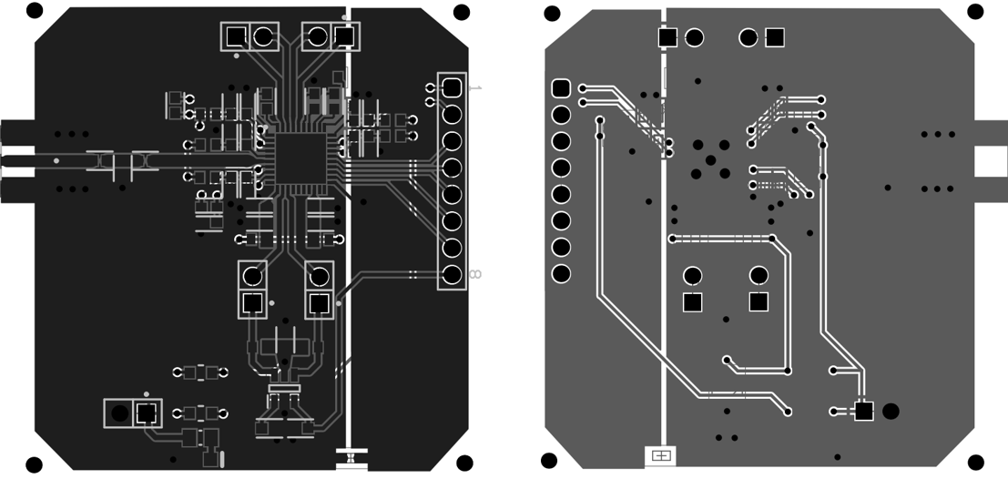
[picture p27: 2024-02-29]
images/layout.png

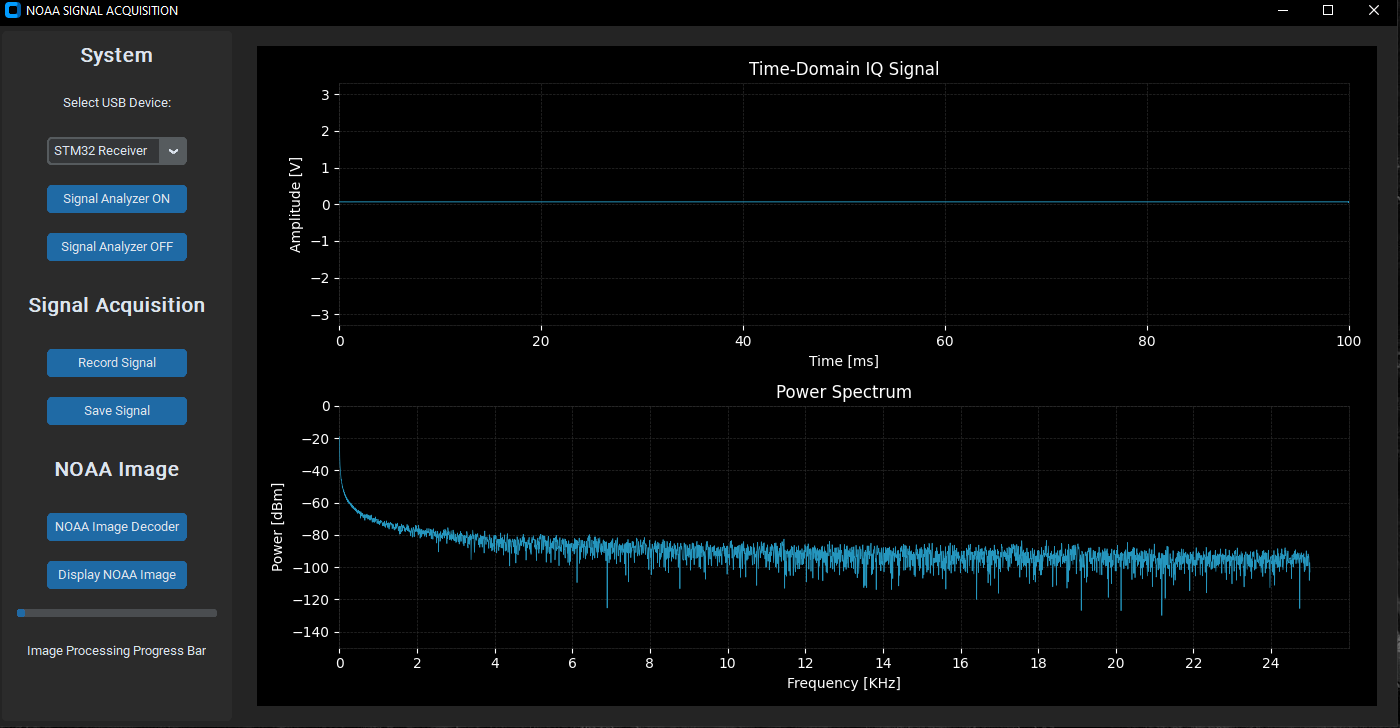
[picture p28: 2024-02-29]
images/gui.png

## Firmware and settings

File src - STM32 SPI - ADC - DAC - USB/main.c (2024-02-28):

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
/* Includes ------------------------------------------------------------------*/
#include "main.h"
#include "usb_device.h"

/* USER CODE BEGIN Includes */
#include "usbd_cdc_if.h"
#include "stdio.h"
#include "spi_cmx994.h"
#include "string.h"
/* USER CODE END Includes */

/* USER CODE BEGIN PD */
#define MAX_DATA_ARRAY_SIZE				20000 	// 14 000 bytes == 50ms of signal

#define MEAS_ADC1_CHANNELS 				1
#define ADC1_OVERSAMLING 				2		// ADC value shifting (oversamling)
#define ADC1_BUFFER_SZ 					8 		// ADC Buffer size per channel



/* USER CODE END PD */

ADC_HandleTypeDef hadc1;
ADC_HandleTypeDef hadc2;
DMA_HandleTypeDef hdma_adc1;

DAC_HandleTypeDef hdac1;

SPI_HandleTypeDef hspi2;

TIM_HandleTypeDef htim8;

/* USER CODE BEGIN PV */
uint16_t ADC1_Buffer[4];						// * 2 --> Double Buffer for DMA
uint16_t ADC1_BufferSize = 4;					// ADC1 "half" Buffer size 4 bytes,
uint8_t data_array[MAX_DATA_ARRAY_SIZE];
uint8_t data_array_copy[MAX_DATA_ARRAY_SIZE];
uint16_t array_index = 0;






/* USER CODE END PV */

void SystemClock_Config(void);
void PeriphCommonClock_Config(void);
static void MX_GPIO_Init(void);
static void MX_DMA_Init(void);
static void MX_ADC1_Init(void);
static void MX_TIM8_Init(void);
static void MX_ADC2_Init(void);
static void MX_SPI2_Init(void);
static void MX_DAC1_Init(void);
/* USER CODE BEGIN PFP */

void HAL_ADC_ConvCpltCallback(ADC_HandleTypeDef* hadc);
void HAL_ADC_ConvHalfCpltCallback(ADC_HandleTypeDef* hadc);

uint8_t MEAS_ADC_start(void);
void MEAS_ADC1_eval(uint8_t pos);


/* USER CODE END PFP */

/* USER CODE BEGIN 0 */

uint8_t MEAS_ADC_start(void) {
	// @brief	start ADC
	// @param	none
	// @return	U8 status, 0=OK (no error)

	uint8_t retval = 0;
	uint8_t s = 0;
	HAL_StatusTypeDef status = HAL_OK;
	HAL_ADCEx_Calibration_Start(&hadc1,ADC_DIFFERENTIAL_ENDED);
	status = HAL_ADCEx_Calibration_Start(&hadc1,ADC_DIFFERENTIAL_ENDED);		// calibrate ADC1
	if(status) retval |= (1 << s);
	s++;
	HAL_ADCEx_Calibration_Start(&hadc2,ADC_DIFFERENTIAL_ENDED);
	status = HAL_ADCEx_Calibration_Start(&hadc2,ADC_DIFFERENTIAL_ENDED);		// calibrate ADC2
	if(status) retval |= (1 << s);
	s++;
	HAL_Delay(10);

	// Start ADC1+ADC2 in Multimode configuration
	HAL_ADC_Start(&hadc2);
	HAL_ADCEx_MultiModeStart_DMA(&hadc1, (uint32_t *)ADC1_Buffer, sizeof(ADC1_Buffer)); 	// start ADC1 /w Double Buffer
	//status = HAL_ADC_Start(&hadc2);																	// start ADC2 (slave) first!
	//status = HAL_ADCEx_MultiModeStart_DMA(&hadc1, (uint32_t *)ADC1_Buffer, sizeof(ADC1_Buffer)); 	// start ADC1 /w Double Buffer

	if(status) retval |= (1 << s);
	s++;

	return(retval);
}

void MEAS_ADC1_eval(uint8_t pos) {

	uint16_t bP = 0;
	if(pos) bP = ADC1_BufferSize;

	memcpy(data_array + array_index, ADC1_Buffer + bP,sizeof(ADC1_Buffer)/2); //
	array_index +=4;


	if (array_index==MAX_DATA_ARRAY_SIZE) {


	    // Transmit the data to the PC
		memcpy(data_array_copy, data_array ,MAX_DATA_ARRAY_SIZE);
		CDC_Transmit_FS((uint8_t *)data_array_copy,MAX_DATA_ARRAY_SIZE);
		memset(data_array, 0, MAX_DATA_ARRAY_SIZE);
		array_index = 0;
	}

}


void HAL_ADC_ConvCpltCallback(ADC_HandleTypeDef* hadc) {

   if(hadc) MEAS_ADC1_eval(1);

}


void HAL_ADC_ConvHalfCpltCallback(ADC_HandleTypeDef* hadc) {

   if(hadc) MEAS_ADC1_eval(0);

}


/* USER CODE END 0 */

/**
  * @brief  The application entry point.
  * @retval int
  */
int main(void)
{
  /* MCU Configuration--------------------------------------------------------*/

  /* Reset of all peripherals, Initializes the Flash interface and the Systick. */
  HAL_Init();

  /* Configure the system clock */
  SystemClock_Config();

/* Configure the peripherals common clocks */
  PeriphCommonClock_Config();

  /* USER CODE BEGIN SysInit */

  /* USER COD E END SysInit */

  /* Initialize all configured peripherals */
  MX_GPIO_Init();
  MX_DMA_Init();
  MX_ADC1_Init();
  MX_TIM8_Init();
  MX_ADC2_Init();
  MX_SPI2_Init();
  MX_DAC1_Init();
  MX_USB_DEVICE_Init();
  /* USER CODE BEGIN 2 */
  HAL_DAC_Start(&hdac1, DAC_CHANNEL_1);
  HAL_DAC_SetValue(&hdac1, DAC_CHANNEL_1, DAC_ALIGN_12B_R,783); ///

  REGISTER_ALL_Init(&hspi2);
  REGISTER_ALL_Read(&hspi2, REGISTER_VALUES);


  HAL_TIM_Base_Start(&htim8);
  MEAS_ADC_start(); // start the ADC conversion
  /* USER CODE END 2 */

  /* Infinite loop */
  /* USER CODE BEGIN WHILE */



  while (1)
  {
    /* USER CODE END WHILE */

    /* USER CODE BEGIN 3 */
//	  HAL_DAC_SetValue(&hdac1, DAC_CHANNEL_1, DAC_ALIGN_12B_R,i); ///
//	  i+=1;
//	  HAL_Delay(500);
//	  if (i==1000){
//		  i=500;
//	  }
  }
  /* USER CODE END 3 */
}

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


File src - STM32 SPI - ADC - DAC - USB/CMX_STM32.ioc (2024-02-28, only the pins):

Mcu.UserName=STM32L476RGTx
PA11.Signal=USB_OTG_FS_DM
PA12.Signal=USB_OTG_FS_DP
PA4.Signal=COMP_DAC11_group
PB10.Signal=SPI2_SCK
PB14.Signal=SPI2_MISO
PB15.Signal=SPI2_MOSI
PB6.GPIO_Label=CS
PB6.Signal=GPIO_Output
PC0.Signal=ADCx_IN1
PC1.Signal=ADCx_IN2
PC2.Signal=ADCx_IN3
PC3.Signal=ADCx_IN4

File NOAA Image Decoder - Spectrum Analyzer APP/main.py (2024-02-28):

import customtkinter as ct
from CTkMessagebox import CTkMessagebox
from tkinter import filedialog

from usb_reader import USB_READER
from signal_analyzer import SIGNAL_ANALYZER
from wav_writer import WAV_WRITER
from noaa_image_decoder import NOAA_IMAGE_DECODER, NOAA_IMAGE_DISPLAY

import numpy as np
from queue import Queue
import matplotlib.pyplot as plt
from matplotlib.animation import FuncAnimation
from matplotlib.backends.backend_tkagg import FigureCanvasTkAgg

import serial.tools.list_ports

class NOAA_APP(ct.CTk):
    def __init__(self):
        super().__init__()
        self.noaa_image = None          #
        self.usb_reader = None          #
        self.plotter = None             #
        self.ani = None                 #
        self.file_name = None           #
        self.file_info_label = None     #
        self.wav_writer = None          #
        self.image_decoder = None       #
        self.image_file_path = None     #
        self.image_display = None       #

        # IQ BUFFERS AND QUEUE
        # self.I_samples = np.zeros(7000 // 2)  # Inphase channel buffer
        # self.Q_samples = np.zeros(7000 // 2)  # Quadrature channel buffer
        self.IQ_queue = Queue()
        self.image_queue = Queue()

        # Inicjalizacja okna
        self.title("NOAA SIGNAL ACQUISITION")
        self.geometry(f"{1400}x{700}")

        # Layout Configuration
        self.grid_columnconfigure(0, weight=0)
        self.grid_columnconfigure(1, weight=1)
        self.grid_rowconfigure(0, weight=1)
        # Layout Configuration

        # Ramka boczna z widgetami
        self.sidebar_frame = ct.CTkFrame(self, width=140)
        self.sidebar_frame.grid(row=0, column=0, rowspan=4, padx=5, pady=5, sticky="nsew")
        self.sidebar_frame.grid_rowconfigure(4, weight=0)

        self.system_label = ct.CTkLabel(self.sidebar_frame, text="System",
                                        font=ct.CTkFont(size=20, weight="bold"))
        self.system_label.grid(row=0, column=0, padx=20, pady=10)

        self.USB_label = ct.CTkLabel(self.sidebar_frame, text="Select USB Device:")
        self.USB_label.grid(row=1, column=0, padx=20, pady=10)

        self.acq_label = ct.CTkLabel(self.sidebar_frame, text="Signal Acquisition",
                                        font=ct.CTkFont(size=20, weight="bold"))
        self.acq_label.grid(row=5, column=0, padx=20, pady=20)

        self.image_label = ct.CTkLabel(self.sidebar_frame, text="NOAA Image",
                                       font=ct.CTkFont(size=20, weight="bold"))
        self.image_label.grid(row=8, column=0, padx=20, pady=20)

        self.pgbar_label = ct.CTkLabel(self.sidebar_frame, text="Image Processing Progress Bar")
        self.pgbar_label.grid(row=12, column=0, padx=20, pady=10)
        # Ramka boczna z widgetami

        # Przyciski do zmiany widoku
        self.USB_combo_box = ct.CTkComboBox(self.sidebar_frame, values=self.usb_devices())
        self.USB_combo_box.grid(row=2, column=0, padx=20, pady=10)
        self.USB_combo_box.bind("<<ComboboxSelected>>", self.start_spectrum_analyzer)

        self.button_spectrum_analyzer_on = ct.CTkButton(self.sidebar_frame, text="Signal Analyzer ON",
                                                        command=self.start_spectrum_analyzer)
        self.button_spectrum_analyzer_on.grid(row=3, column=0, padx=15, pady=10)

        self.button_spectrum_analyzer_off = ct.CTkButton(self.sidebar_frame, text="Signal Analyzer OFF",
                                                         command=self.stop_spectrum_analyzer)
        self.button_spectrum_analyzer_off.grid(row=4, column=0, padx=15, pady=10)

        self.button_record_signal = ct.CTkButton(self.sidebar_frame, text="Record Signal",
                                                 command=self.start_writing_to_bin_file)
        self.button_record_signal.grid(row=6, column=0, padx=15, pady=10)

        self.button_save_signal = ct.CTkButton(self.sidebar_frame, text="Save Signal",
                                               command=self.stop_writing_to_bin_file)
        self.button_save_signal.grid(row=7, column=0, padx=15, pady=10)

        self.button_image = ct.CTkButton(self.sidebar_frame, text="NOAA Image Decoder",
                                         command=self.open_noaa_image_decoder)
        self.button_image.grid(row=9, column=0, padx=15, pady=10)

        self.button_save_image = ct.CTkButton(self.sidebar_frame, text="Display NOAA Image",
                                              command=self.display_noaa_image)
        self.button_save_image.grid(row=10, column=0, padx=15, pady=10)

        self.progress_bar = ct.CTkProgressBar(master=self.sidebar_frame, orientation="horizontal")
        self.progress_bar.grid(row=11, column=0, padx=15, pady=10)
        self.progress_bar.set(0)


        # Przyciski do zmiany widoku

        # ramka
        self.fft_frame = ct.CTkFrame(self, height=250)
        self.fft_frame.grid(row=0, column=1, padx=20, pady=20, sticky="nsew")

        self.fig, self.ax = plt.subplots(nrows=2, ncols=1, figsize=(4, 2), facecolor='black')
        self.canvas = FigureCanvasTkAgg(self.fig, master=self.fft_frame)
        self.canvas.get_tk_widget().pack(fill="both", expand=True)
        self.ax[0].set_facecolor('black')
        self.ax[1].set_facecolor('black')

        # ramka

        # progress image

        # progress image

        # error flags
        self.analyzer_flag = False
        self.writer_flag = False
        self.noaa_image_flag = False
        # error flags

    def start_spectrum_analyzer(self):
        """

        :param

        :return:
        """
        device = self.USB_combo_box.get()

        if(device == 'STM32 Receiver'):
            if self.analyzer_flag is False:
                self.usb_reader = USB_READER(self.IQ_queue)
                self.usb_reader.start()
                self.plotter = SIGNAL_ANALYZER(self.IQ_queue,self.fig,self.ax, self.fft_frame)
                self.plotter.start()
                self.ani = FuncAnimation(self.fig, self.plotter.update_plot, init_func=self.plotter.init_plot, frames=200,interval=10, blit=True)
                self.analyzer_flag = True
            else:
                CTkMessagebox(message="Signal Analyzer Already Running.", icon='warning', option_1="Thanks")
        else:
            CTkMessagebox(message="Select STM32 Receiver.", icon='warning', option_1="Thanks")
    def stop_spectrum_analyzer(self):
        """

        :param

        :return:
        """

        if self.analyzer_flag is True:
            self.ani.event_source.stop()
            self.plotter.stop()
            self.usb_reader.stop()
            self.analyzer_flag = False
        else:
            CTkMessagebox(message="Signal Analyzer Already Stopped.", icon='warning', option_1="Thanks")

    def start_writing_to_bin_file(self):
        """

        :param
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

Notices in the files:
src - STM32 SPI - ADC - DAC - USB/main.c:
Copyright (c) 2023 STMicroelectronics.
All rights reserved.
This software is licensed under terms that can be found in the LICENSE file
